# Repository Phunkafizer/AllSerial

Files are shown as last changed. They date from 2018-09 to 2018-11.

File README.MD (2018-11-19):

# AllSerial
An universal sophisticated USB-serial converter
Over the course of time I had to work with many different devices which had to be connected via a kind of serial interface. There are lots of different cheap USB-serial adapters available, but no adapter was including all features I needed in a single device. Every USB-serial adapter has in common the USB Controller. So I came up with the idea having a masterboard providing all the common features like USB interface, isolation and diagnostic elements. The most used interfaces (RS232, RS485, TTL UART, TTY current loop & LIN) are build up on slave modules which can be plugged into the mainboard. If a custom interface is needed, there is an EAGLE lib available making it easy to it on your own. 

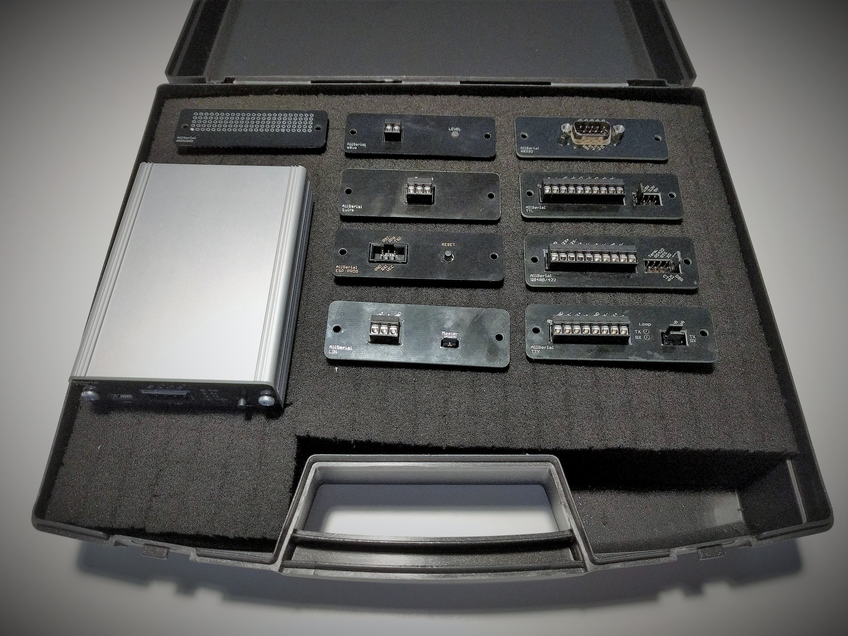
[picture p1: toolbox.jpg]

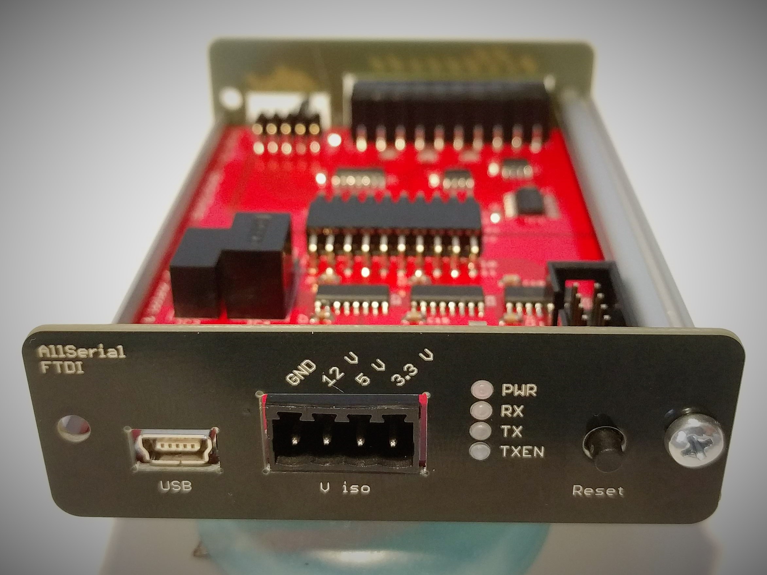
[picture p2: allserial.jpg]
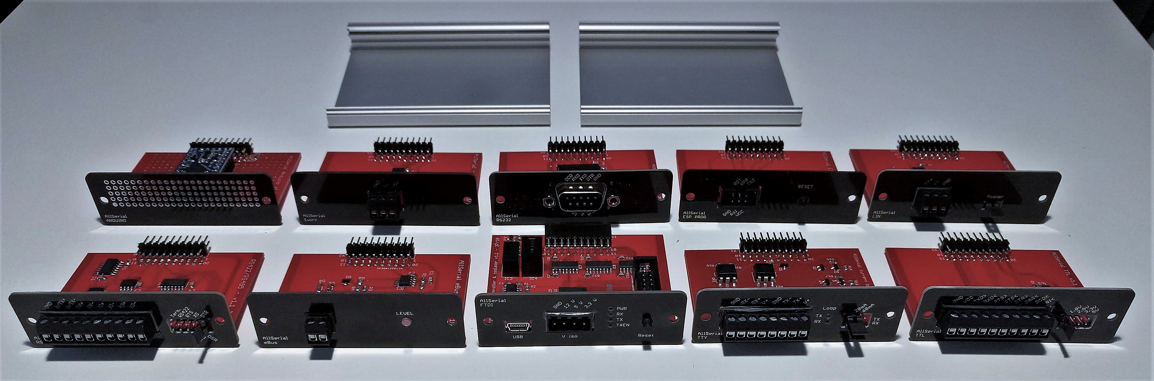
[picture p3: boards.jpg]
 

## Features
- Open source
- Isolated
- Reset button for reenumerating device on the USB
- Status LEDs (RX, TX, Power, TXEN)
- modular, just exchange daughterboard for different interfaces
- RS232 completley connected (RXD, TXD, RTS, CTS, DTR, DSR, RI, DCD)
- RS485, RS422 with Handshake
- TTY current loop 4/3/2 wire active/passive
- LIN
- TTL 1.8/2.5/3.3/5 V
- EAGLE lib for easily creating custom modules

# Modules (tested & working)
* [Mainboard FT232](1A_MAIN_FTDI/)
* [RS 422/485](2_RS485_RS422/)
* [RS 232](3_RS232/)
* [TTL](4_TTL/)
* [TTY current loop](5_TTY/)
* [LIN](6_LIN/)
* [eBus](8_eBus/)
* [1wire (with DS2480B)](9_1wire/)
* [Arduino pro mini clone for custom interfaces](10_ARDUINO/)
* [Programmer for ESP8266 (auto reset&boot)](11_ESP/)

# Modules (planned)
* mBus master

# Software
* [hterm](http://www.der-hammer.info/terminal/) (windows)
* [putty](https://www.chiark.greenend.org.uk/~sgtatham/putty/latest.html) (windows/unix)

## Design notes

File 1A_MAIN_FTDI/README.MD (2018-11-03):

# AllSerial Mainboard FT232
AllSerial Mainboard with FTDI FT232

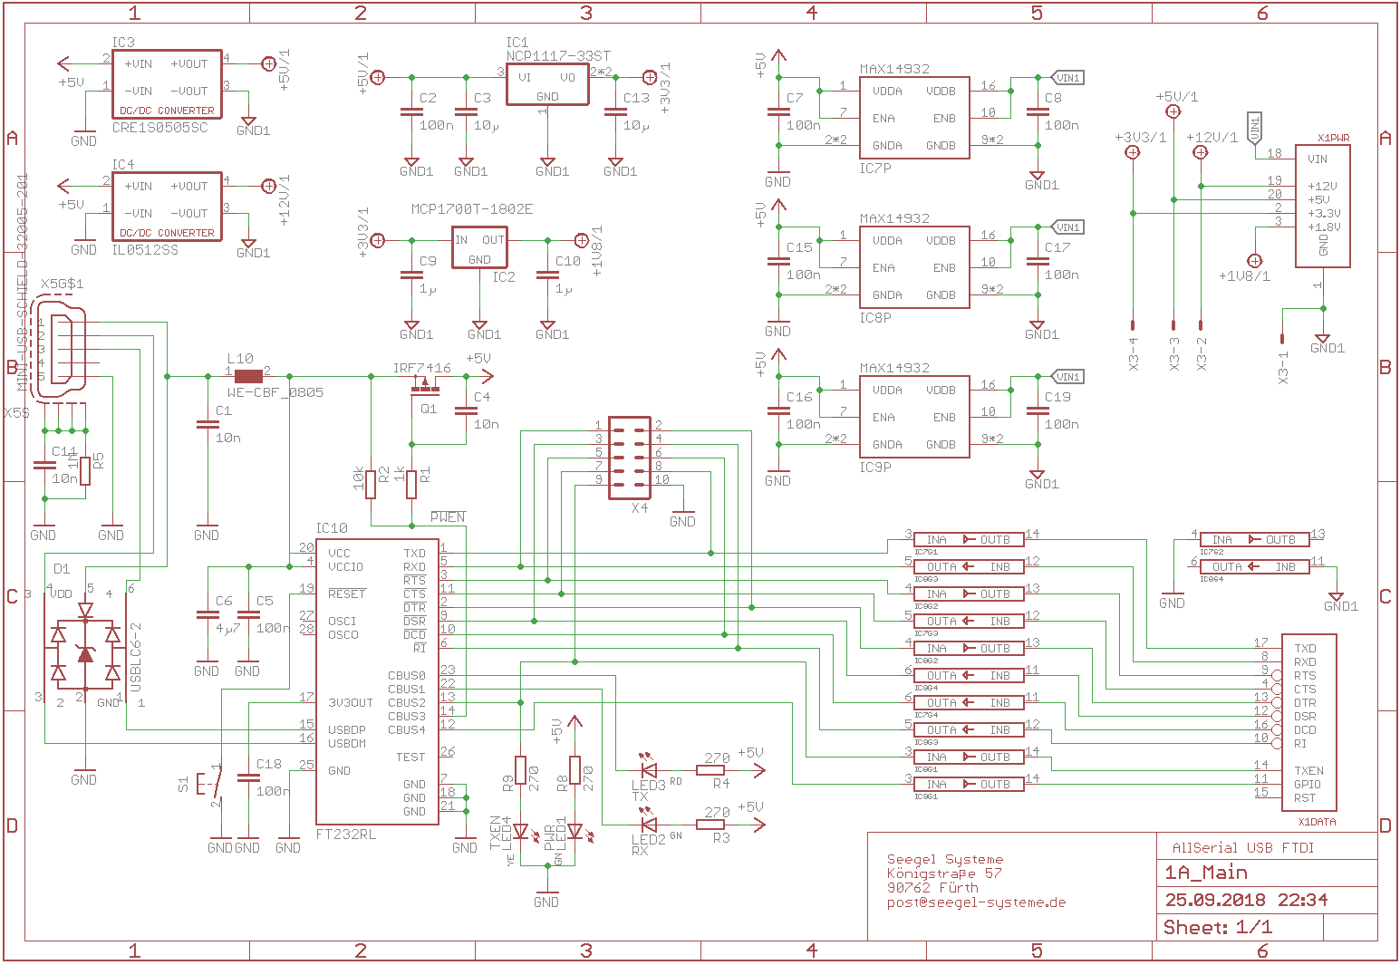
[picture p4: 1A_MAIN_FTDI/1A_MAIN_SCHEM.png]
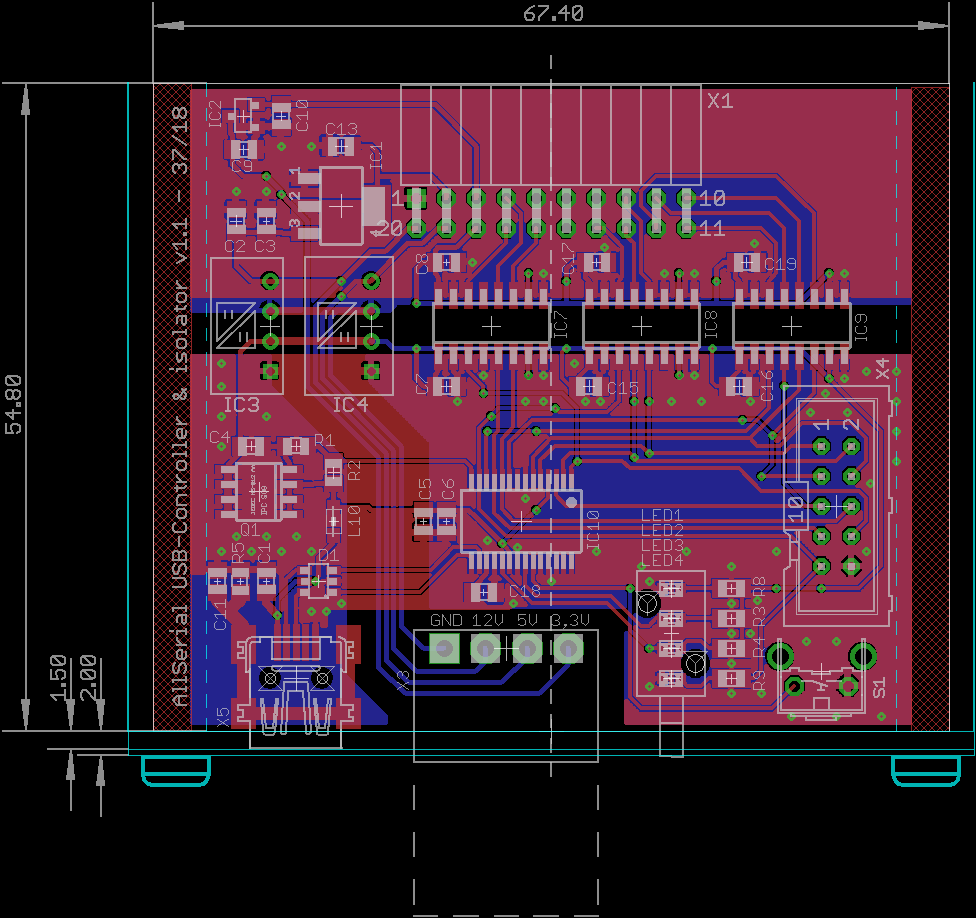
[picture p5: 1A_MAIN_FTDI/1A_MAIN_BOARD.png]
 

* Isolated between controller and daughterboards
* Connector for isolated supply 3.3 / 5 / 12 V
* LEDs for TX/RX/POWER
* 10 pin connector for logic analyser
* Reset button for reenumerating device
* Disconnects power on USB standby

Reichelt Warenkorb: https://www.reichelt.de/my/1489962

USB hardware design guide for FTDI ICs: https://www.ftdichip.com/Support/Documents/AppNotes/AN_146_USB_Hardware_Design_Guidelines_for_FTDI_ICs.pdf

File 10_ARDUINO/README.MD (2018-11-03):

# 10 development board for Arduino Pro Mini

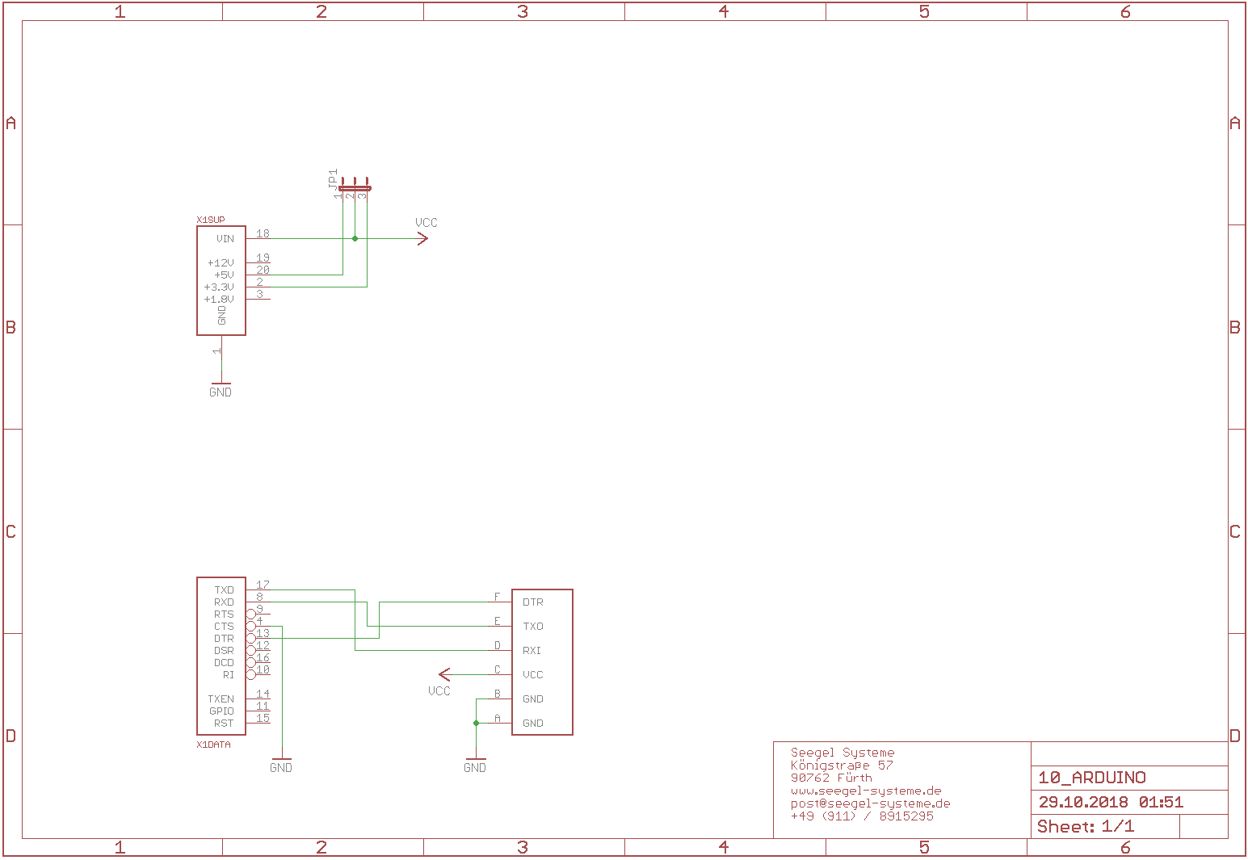
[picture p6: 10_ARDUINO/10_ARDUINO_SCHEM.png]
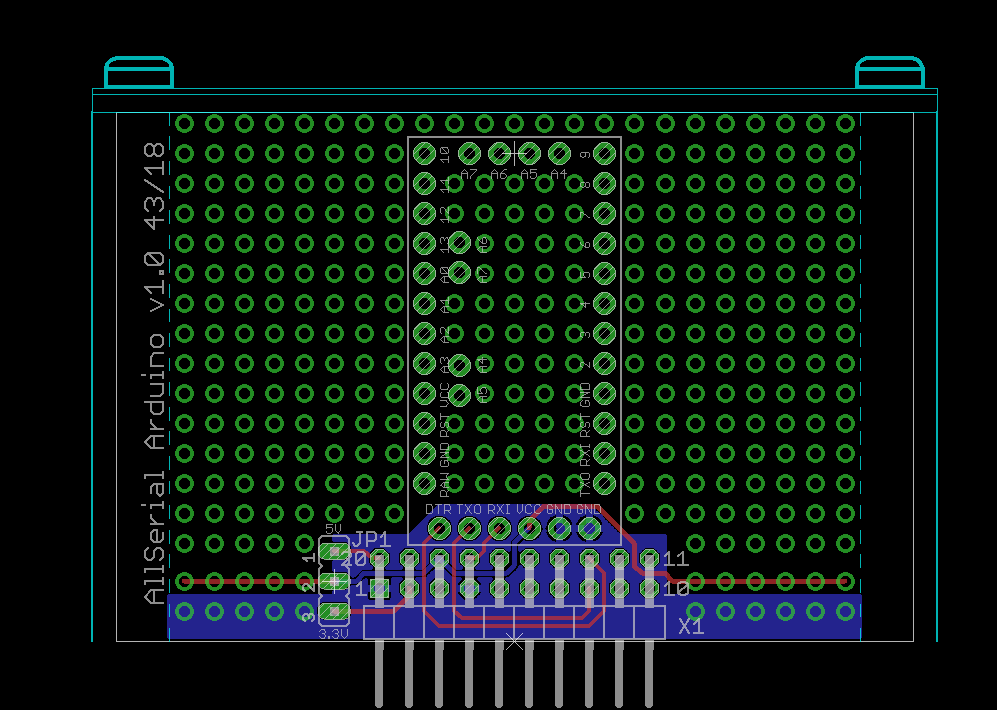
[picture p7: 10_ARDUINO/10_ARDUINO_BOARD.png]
 
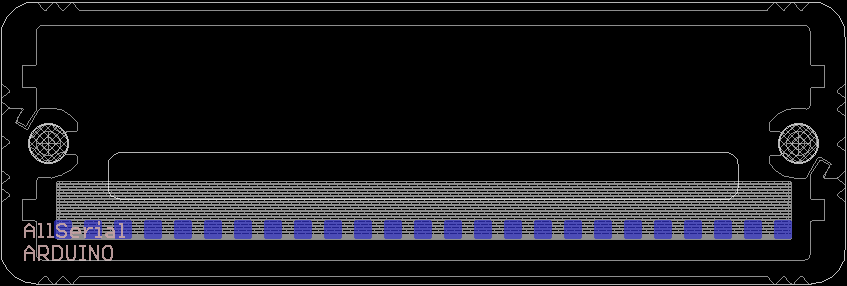
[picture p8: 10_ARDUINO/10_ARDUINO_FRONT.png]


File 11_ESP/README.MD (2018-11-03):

# 11 programmer for ESP32

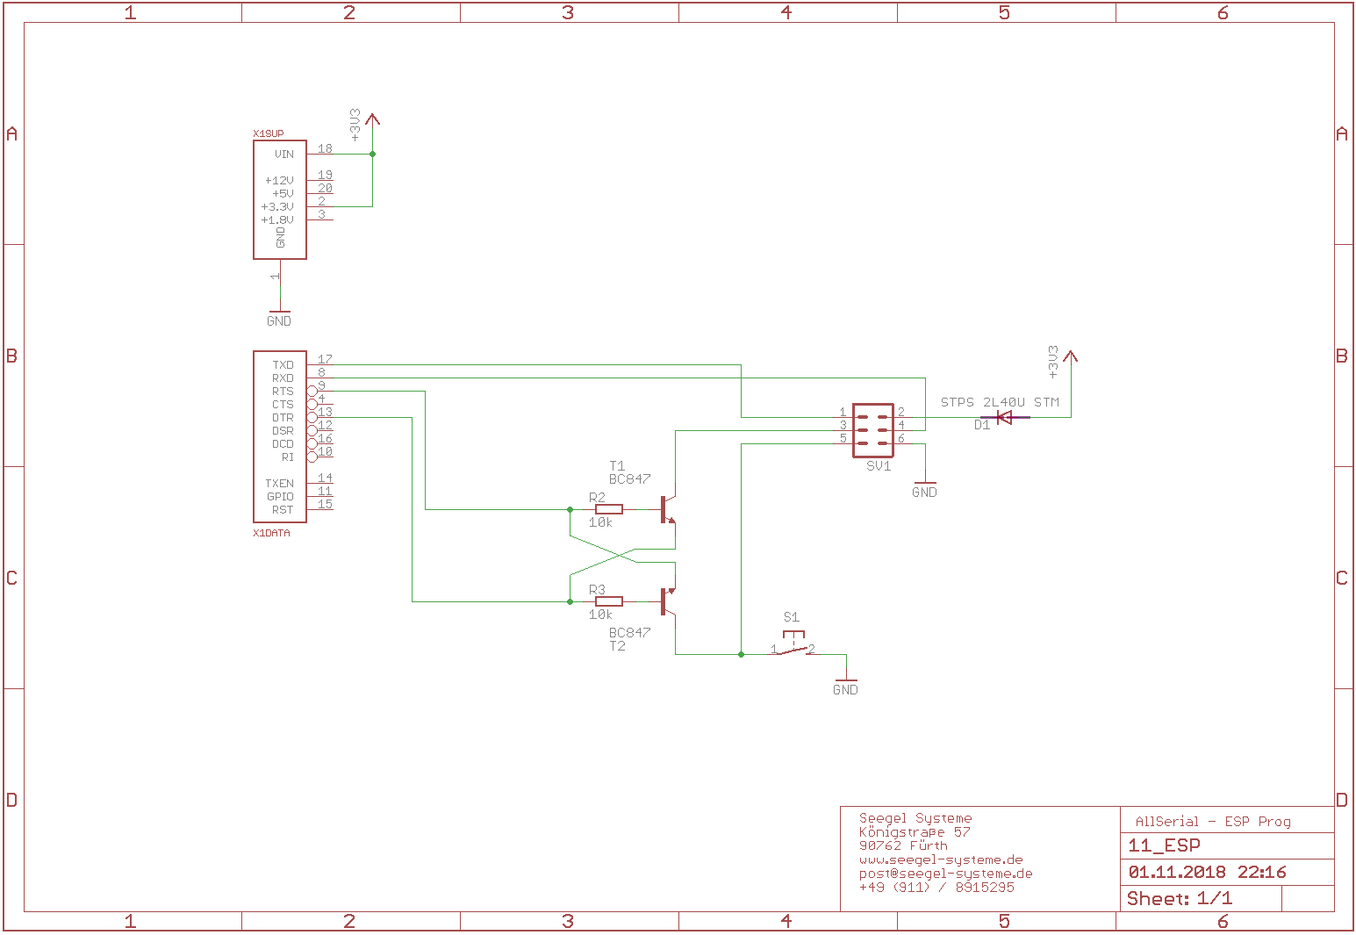
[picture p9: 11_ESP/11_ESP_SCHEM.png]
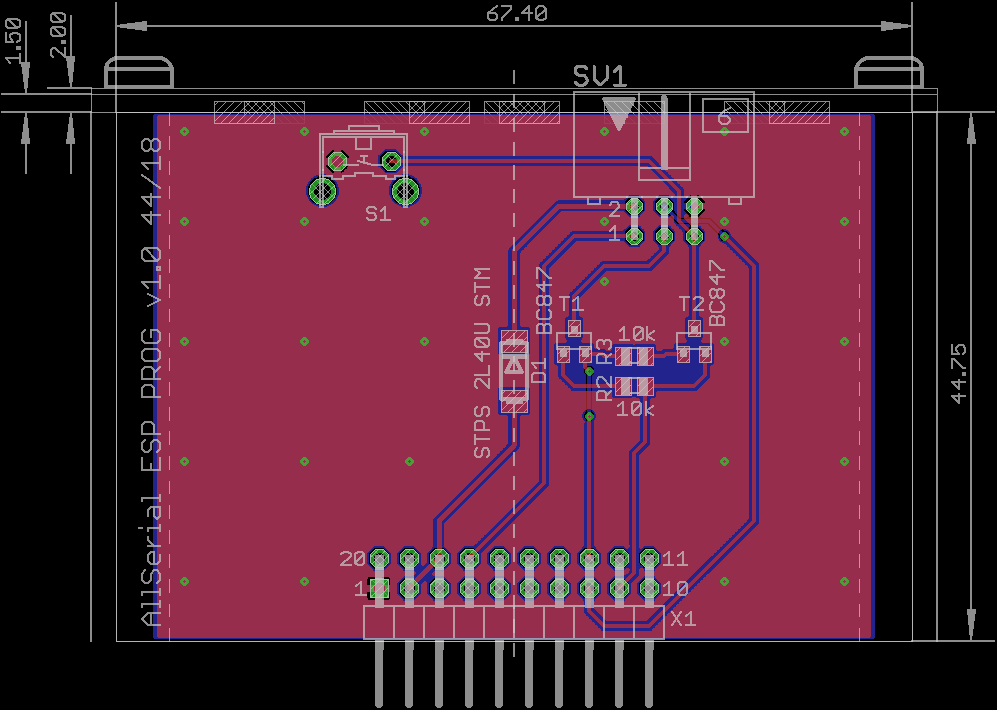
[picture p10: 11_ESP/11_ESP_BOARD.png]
 
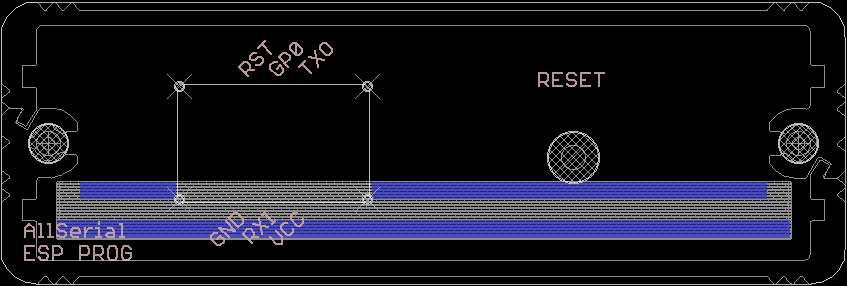
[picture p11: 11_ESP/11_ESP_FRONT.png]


* controls reset & gpio0 lines

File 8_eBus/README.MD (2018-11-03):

# 8 eBus
provides a eBus interface

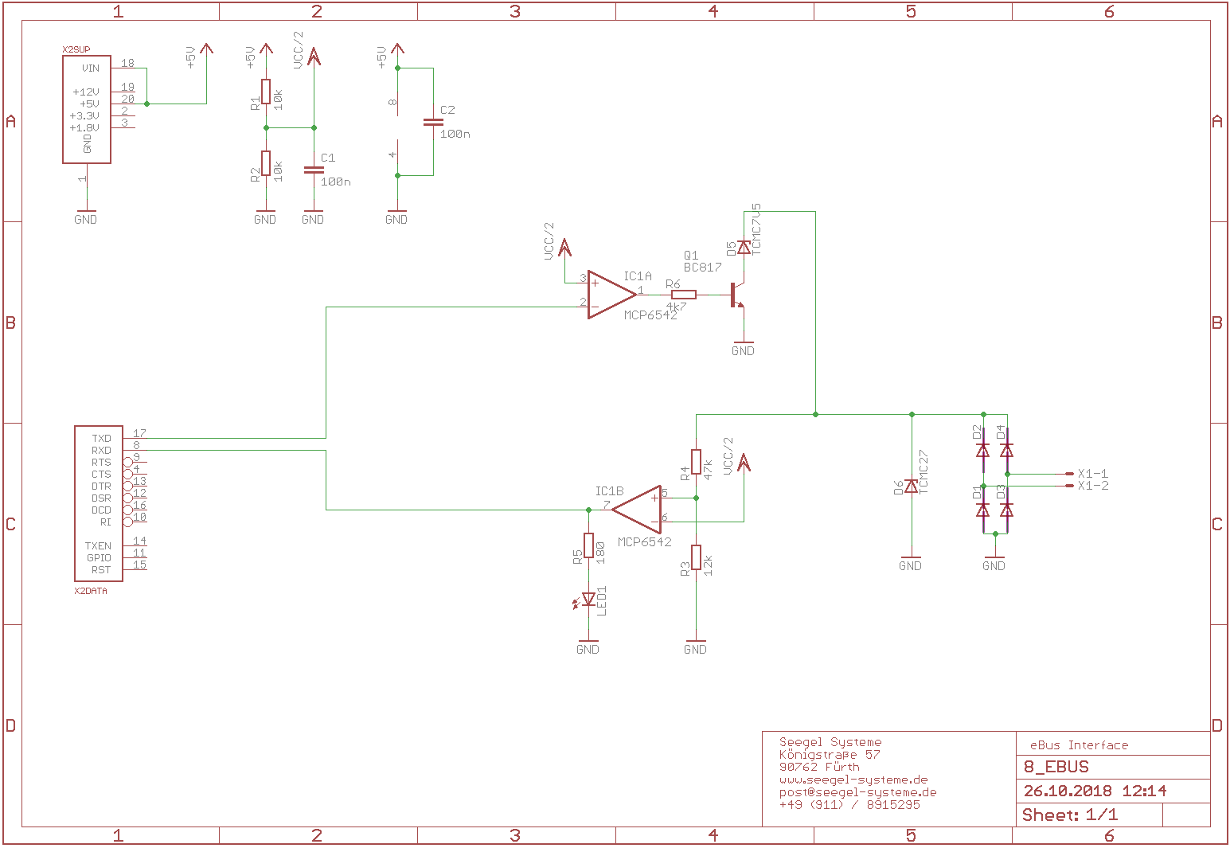
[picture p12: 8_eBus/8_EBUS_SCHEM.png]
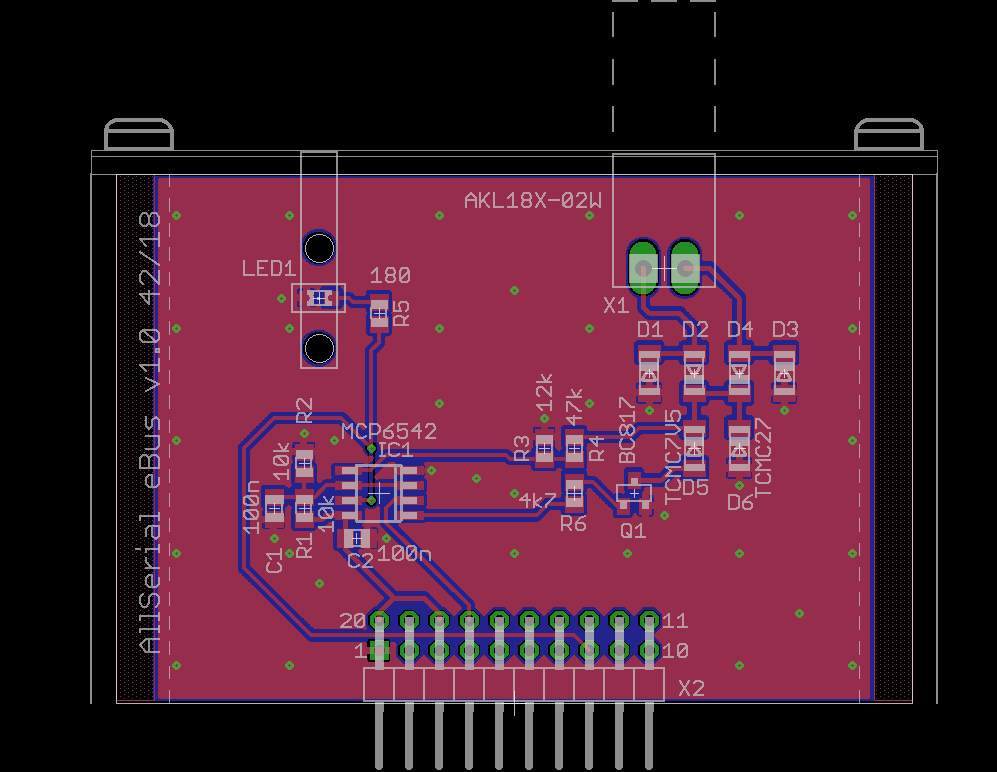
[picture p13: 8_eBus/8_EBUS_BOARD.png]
 
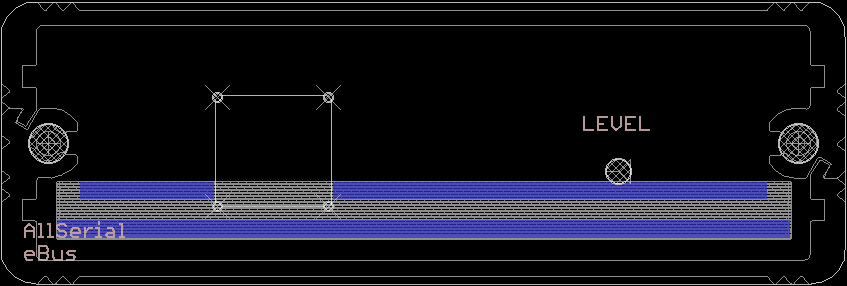
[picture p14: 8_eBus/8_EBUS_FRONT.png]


* no level adjustment needed
* LED for state of level

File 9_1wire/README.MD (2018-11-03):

# 9 1wire
provides a 1-wire interface

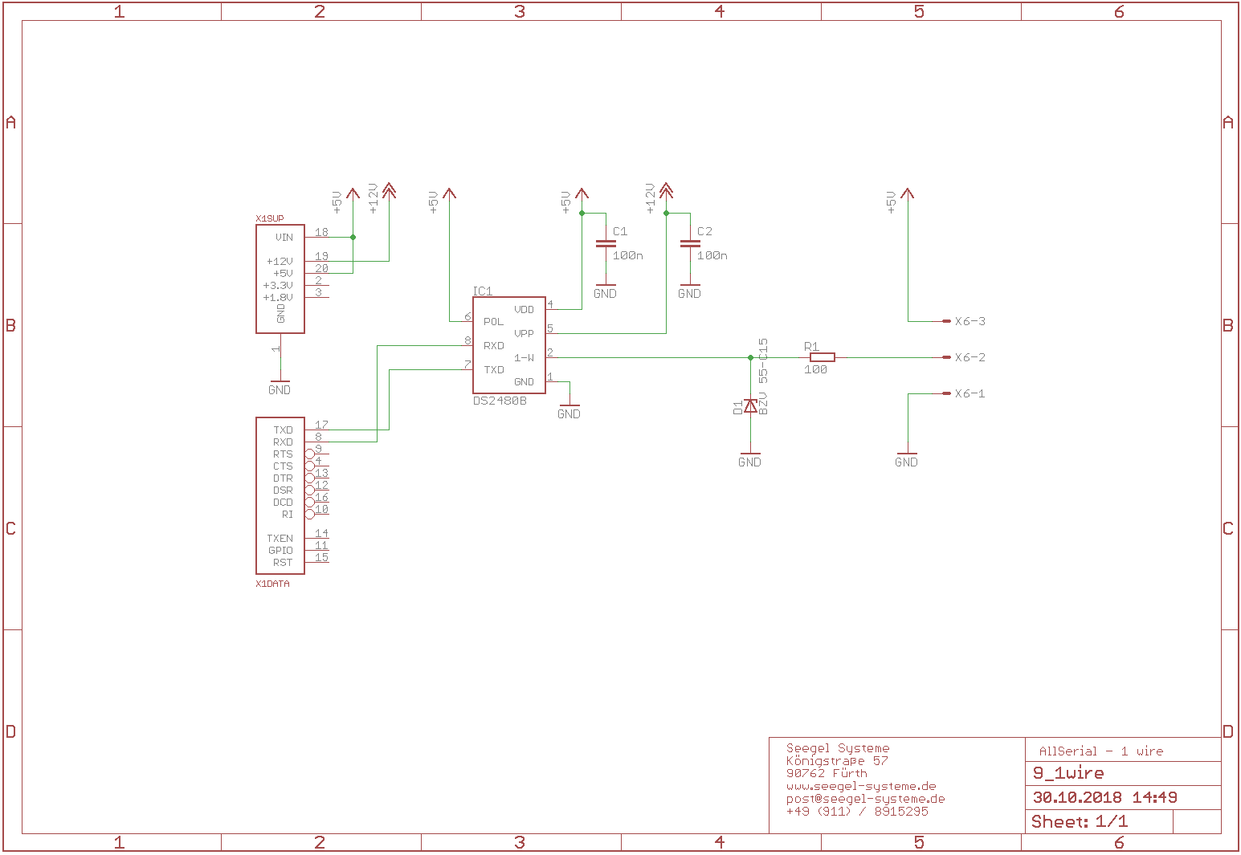
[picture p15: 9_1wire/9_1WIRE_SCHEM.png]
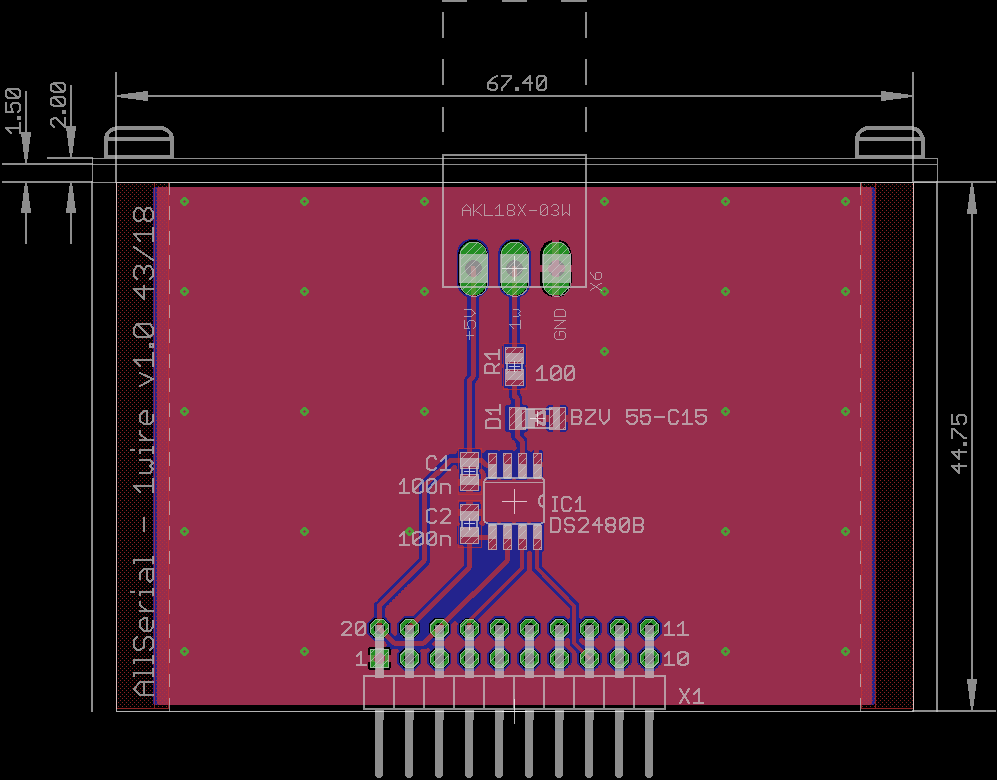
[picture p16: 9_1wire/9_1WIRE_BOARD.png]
 
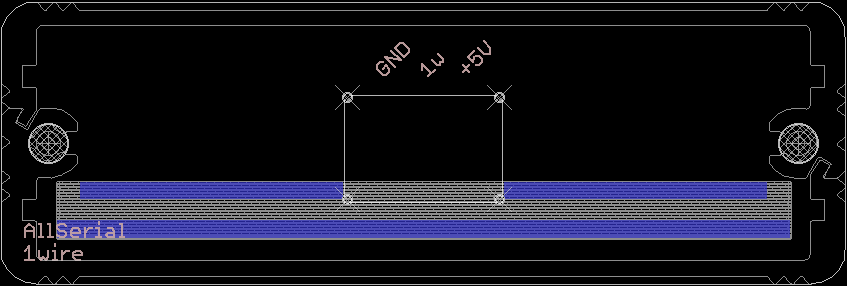
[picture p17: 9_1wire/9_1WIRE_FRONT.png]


* using IC DS2480B
* provides 12 V for programming 1wire eeproms

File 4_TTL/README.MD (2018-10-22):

# TTL connector
The TTL connector module provides all UART pins on a 3.5 mm screwclamp

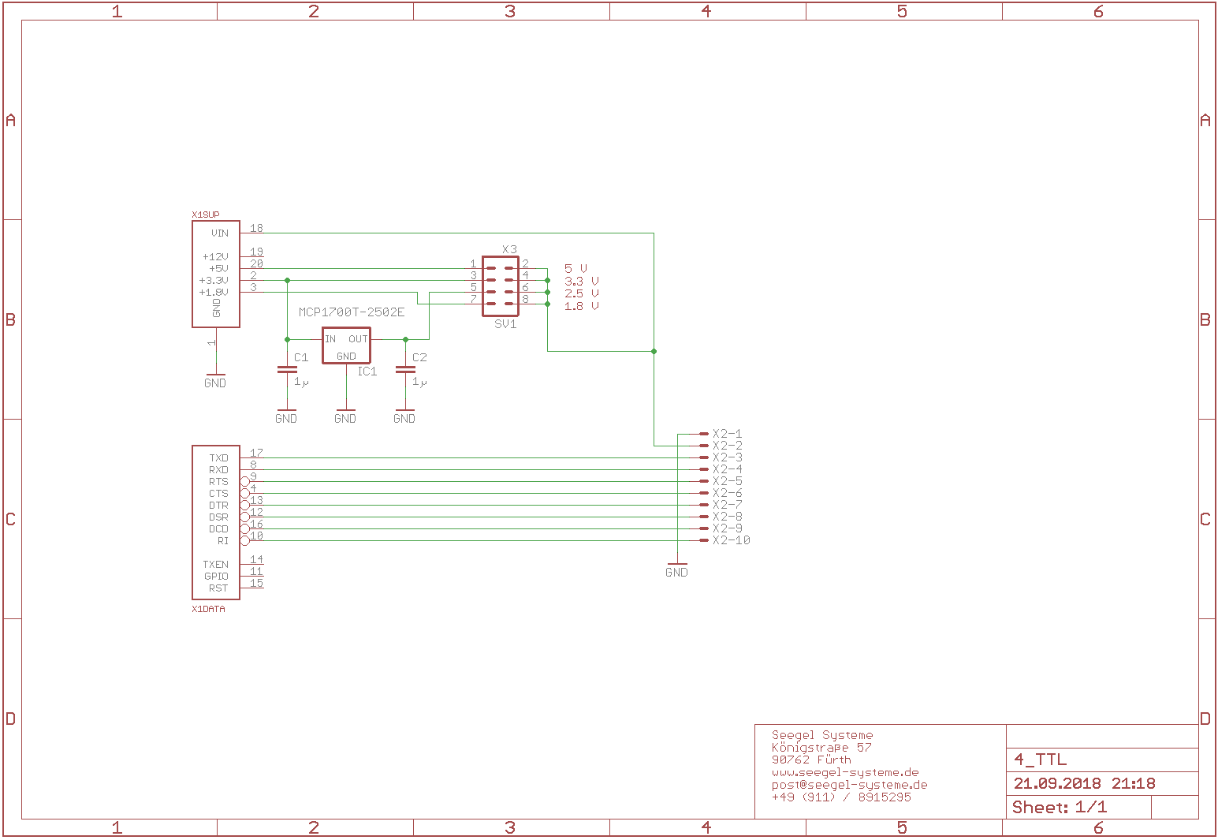
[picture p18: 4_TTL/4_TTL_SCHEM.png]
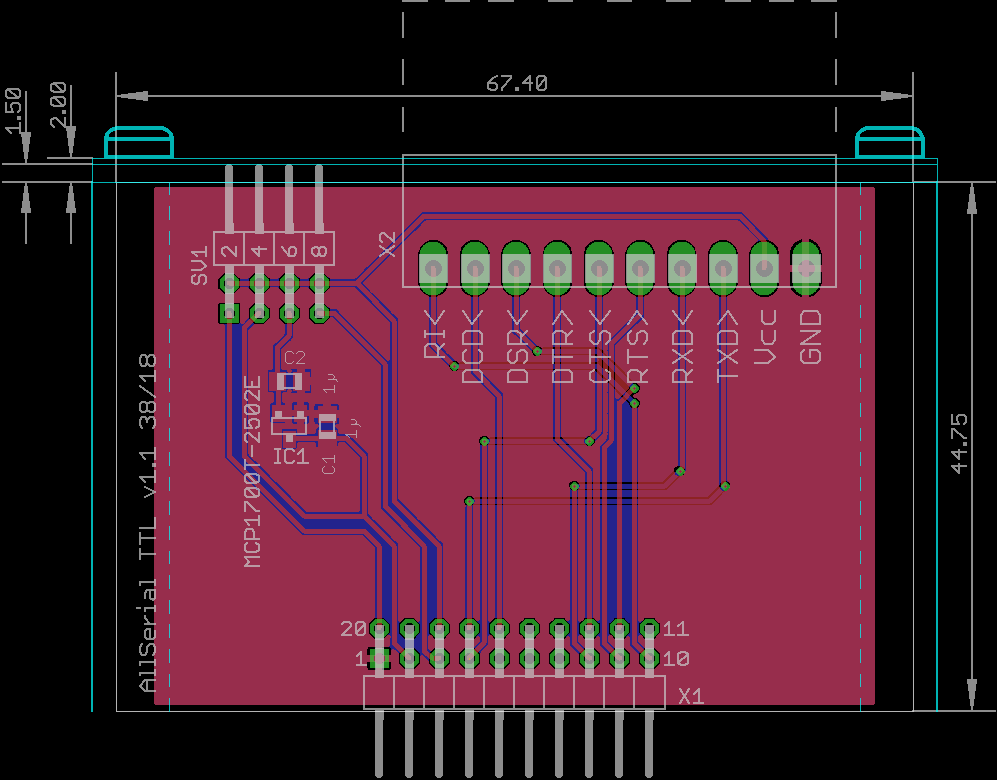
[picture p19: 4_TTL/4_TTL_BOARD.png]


* Full connection: TXD, RXD, CTS, RTS, DTR, DSR, DCD, RI
* Selectable voltage 5 V, 3.3 V, 2.5 V, 1.8 V, external

Reichelt Warenkorb: https://www.reichelt.de/my/1490024

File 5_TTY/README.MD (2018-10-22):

# Current loop (TTY) interface

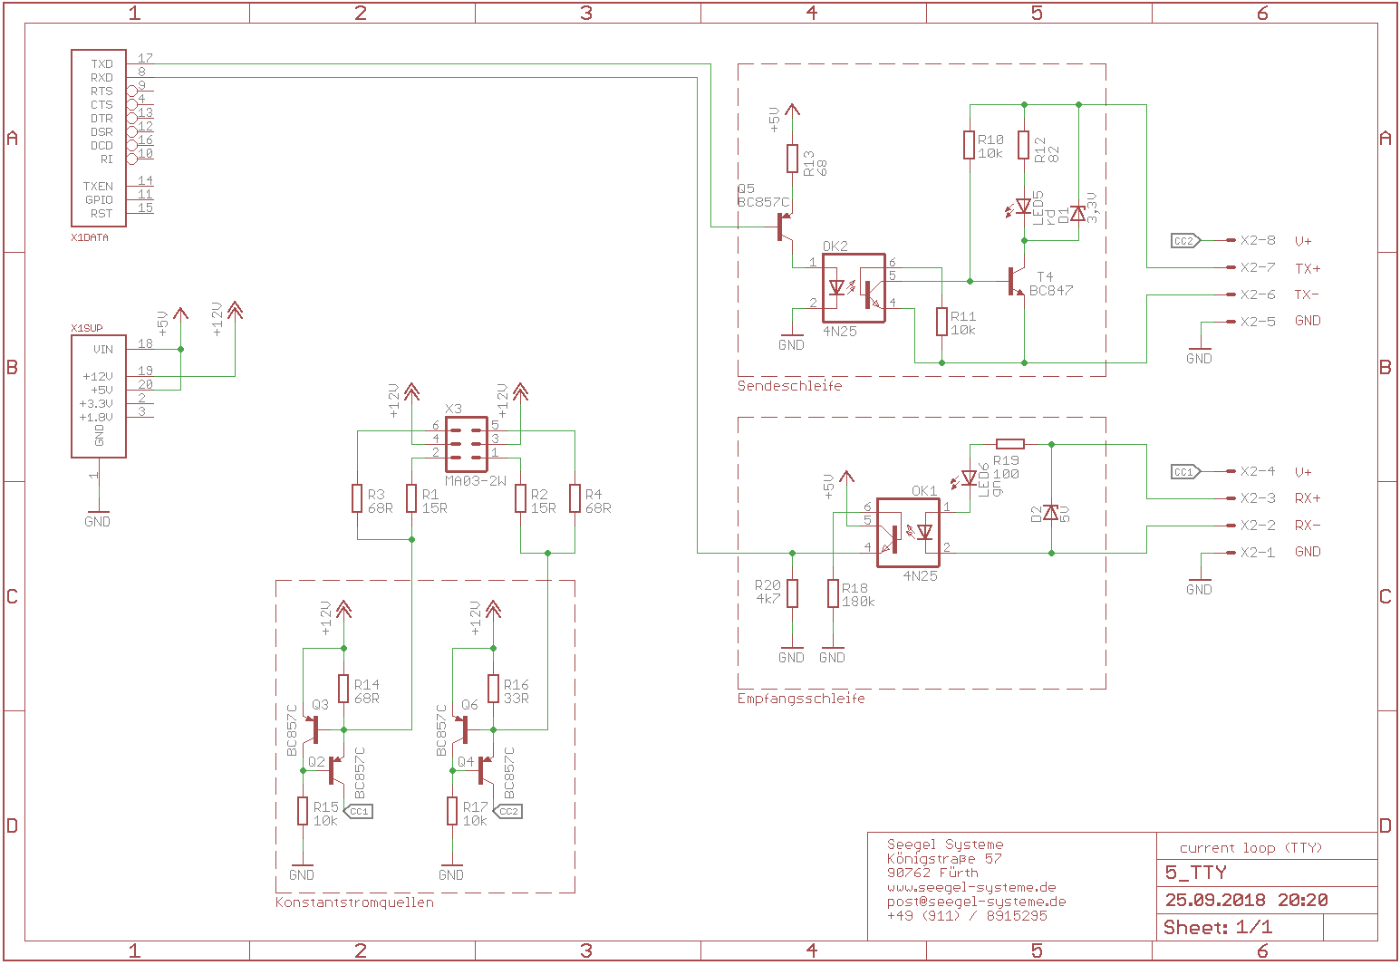
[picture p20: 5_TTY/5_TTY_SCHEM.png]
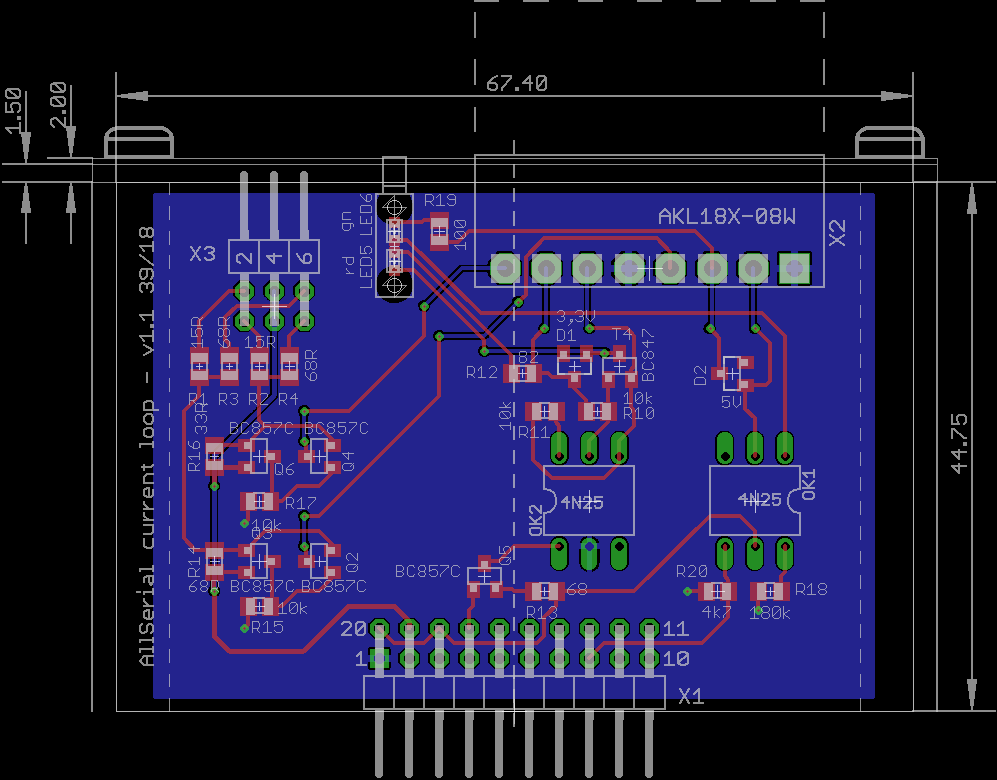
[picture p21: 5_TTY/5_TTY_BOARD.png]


* Jumper for mode (2/3/4-wire, passiv/active)
* Jumper for currentselection (5 / 20 / 60 mA)

Reichelt Warenkorb: https://www.reichelt.de/my/1490298

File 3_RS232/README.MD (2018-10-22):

# RS232
Provides a RS 422 interface (DTE)

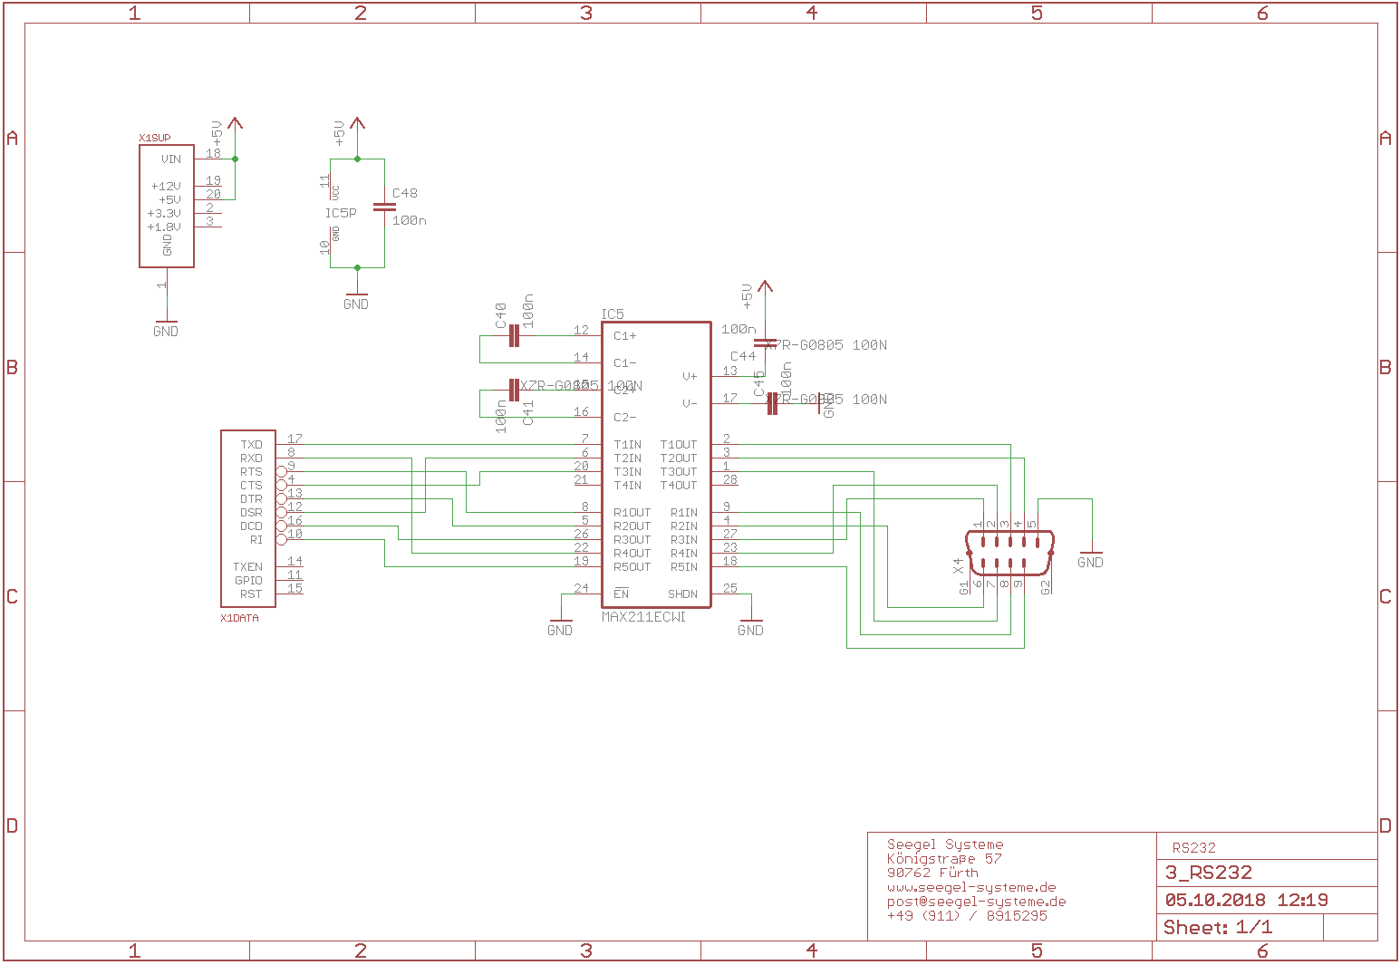
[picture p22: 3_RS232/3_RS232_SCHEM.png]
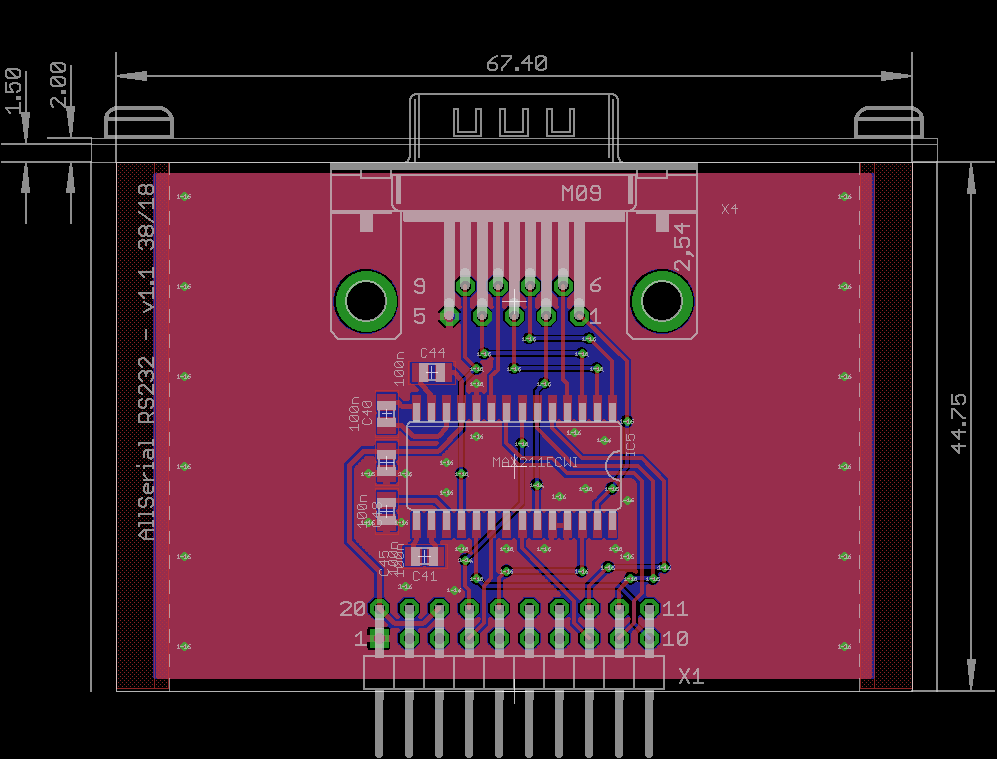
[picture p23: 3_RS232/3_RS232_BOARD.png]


* fully connected (TX, RX, RTS, CTS, DTR, DSR, RI, DCD)
* 9 pin D-SUB male connector

Reichelt Warenkorb: https://www.reichelt.de/my/1490023

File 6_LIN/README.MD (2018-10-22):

# 6 LIN
provides a LIN interface

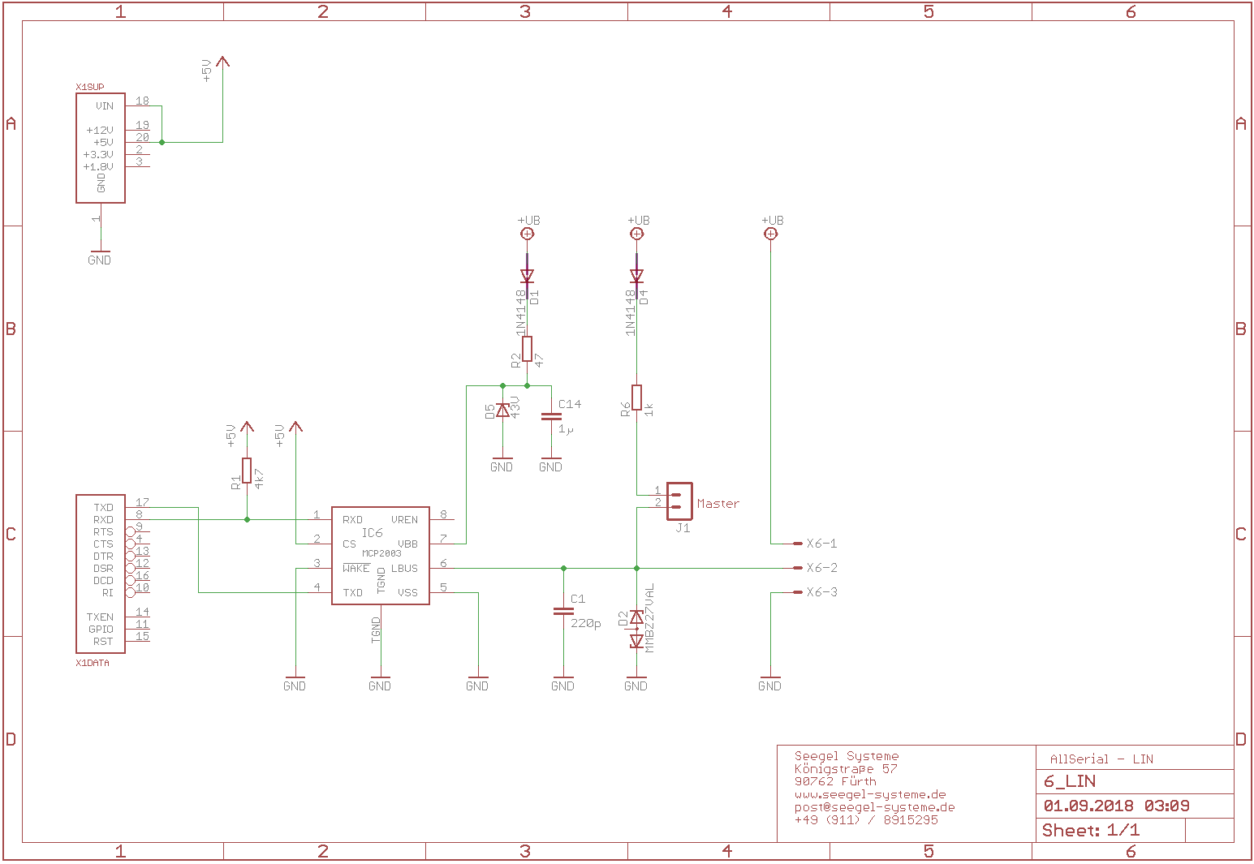
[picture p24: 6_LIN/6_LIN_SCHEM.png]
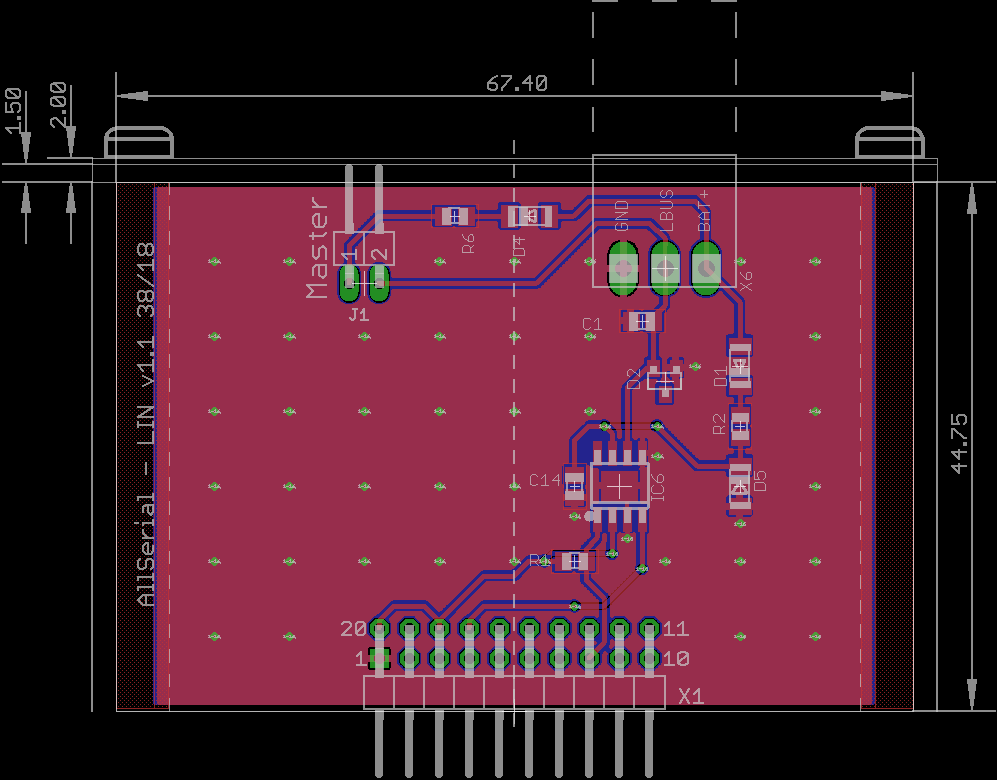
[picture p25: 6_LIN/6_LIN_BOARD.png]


* Jumper for operate as master

Reichelt Warenkorb: https://www.reichelt.de/my/1512118

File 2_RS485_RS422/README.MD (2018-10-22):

# AllSerial RS 422/485 module
Provides a RS 485/422 interface

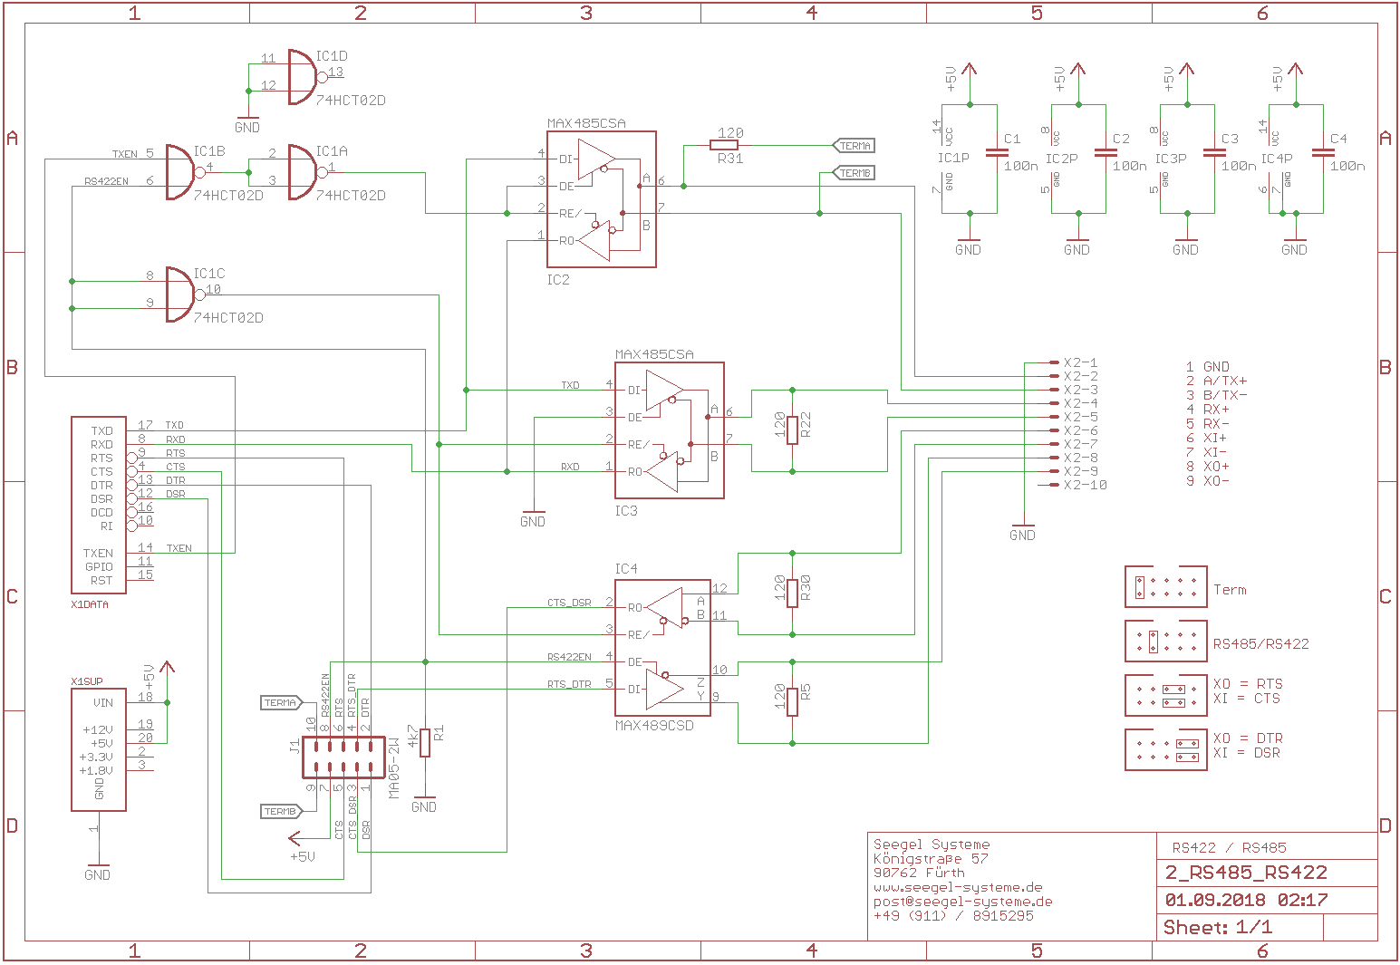
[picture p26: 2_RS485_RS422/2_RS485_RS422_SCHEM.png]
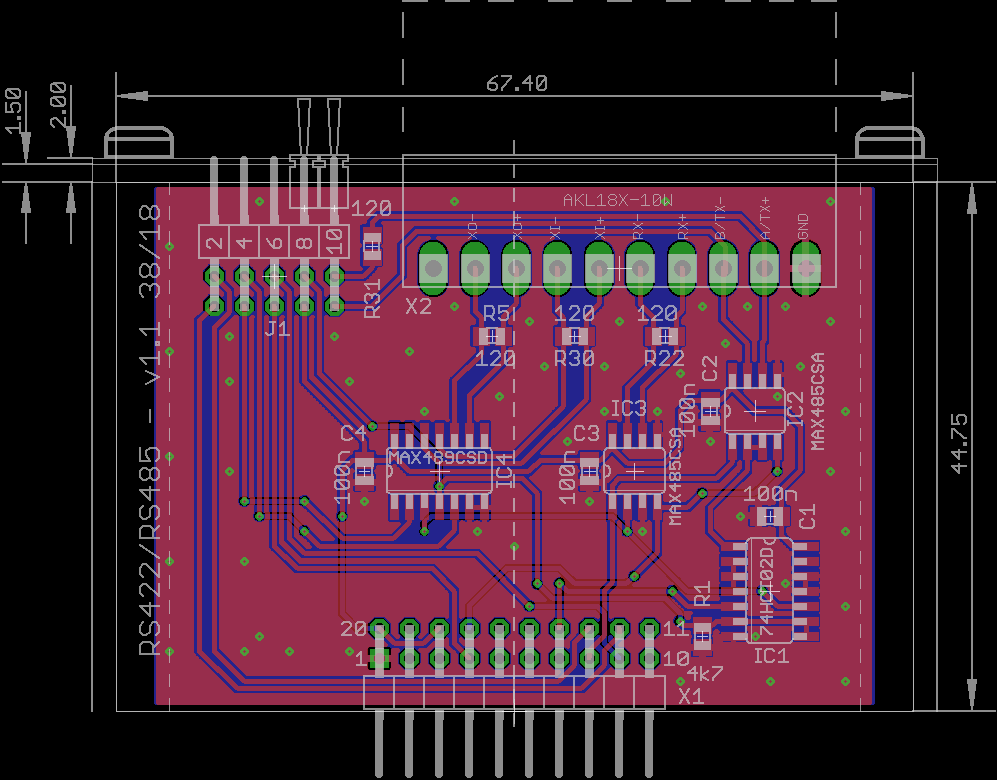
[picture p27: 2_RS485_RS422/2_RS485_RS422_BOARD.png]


* Jumper for termination
* Additional doublepair for RS422 with handshake lines
* RTS/DTR CTS/DSR for handshake can be select with jumper

Reichelt Warenkorb: https://www.reichelt.de/my/1489968

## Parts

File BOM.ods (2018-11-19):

Board | Qty | Value | Device | Package | Parts | Description | OC_REICHELT | OC_FARNELL | PRICE | PRICE_SUM | Unique | Pads
1A_MAIN
 | 1 | 1k | R-EU_R0805 | R0805 | R1 | RESISTOR, European symbol | SMD-0805 1,00K |  | 0,03 € | 0,03 € | 1 | 2
 | 1 | 10k | R-EU_R0805 | R0805 | R2 | RESISTOR, European symbol | SMD-0805 10,0K |  | 0,03 € | 0,03 € | 1 | 2
 | 4 | 270 | R-EU_R0805 | R0805 | R3, R4, R8, R9 | RESISTOR, European symbol | SMD-0805 270 |  | 0,03 € | 0,12 € | 1 | 2
 | 1 | 1M | R-EU_R0805 | R0805 | R5 | RESISTOR, European symbol | SMD-0805 1,00M |  | 0,03 € | 0,03 € | 1 | 2
 | 3 | 10n | C-EUC0805 | C0805 | C1, C4 | CAPACITOR, European symbol | X7R-G0805 10N |  | 0,01 € | 0,03 € | 1 | 2
 | 9 | 100n | C-EUC0805 | C0805 | C2, C5, C7, C8, C15, C16, C17, C18, C19 | CAPACITOR, European symbol | X7R-G0805 100N |  | 0,03 € | 0,27 € | 1 | 2
 | 2 | 1µ | C-EUC0805 | C0805 | C9, C10 | CAPACITOR, European symbol | X7R-G0805 1,0/25 |  | 0,04 € | 0,08 € | 1 | 2
 | 1 | 4µ7 | C-EUC0805 | C0805 | C6 | CAPACITOR, European symbol | Y5V 0805 DC 4,7U |  | 0,03 € | 0,03 € | 1 | 2
 | 2 | 10µ | C-EUC0805 | C0805 | C3, C13 | CAPACITOR, European symbol | KEM X5R0805 10U |  | 0,04 € | 0,08 € | 1 | 2
 | 1 | WE-CBF_0805 | WE-CBF_0805 | 805 | L10 | SMD EMI Suppression Ferrite Beads WE-CBF | BLM21PG 300 |  | 0,04 € | 0,04 € | 1 | 2
 | 1 | USBLC6-2 | WE-TVS_82400102 | WE-TVS_SOT23-6L | D1 | TVS Diode Array WE-TVS, High Speed Series |  | 1295310 | 0,28 € | 0,28 € | 1 | 6
 | 1 | PWR | LEDCHIPLED_0603 | CHIPLED_0603 | LED1 | LED gn | EVL 19-21SYGC |  | 0,06 € | 0,06 € | 1 | 2
 | 1 | RX | LEDCHIPLED_0603 | CHIPLED_0603 | LED2 | LED gn | EVL 19-21SYGC |  | 0,06 € | 0,06 € | 1 | 2
 | 1 | TX | LEDCHIPLED_0603 | CHIPLED_0603 | LED3 | LED rd | LED EL 0603 RT |  | 0,07 € | 0,07 € | 1 | 2
 | 1 | TXEN | LEDCHIPLED_0603 | CHIPLED_0603 | LED4 | LED yl | RND 135-00046 |  | 0,05 € | 0,05 € | 1 | 2
 | 1 | IRF7416 | P-MOSFET-SO8 | SO-08 | Q1 | P-Channel MOSFET | IRF 7416 |  | 0,39 € | 0,39 € | 1 | 8
 | 3 | MAX14932BASE+ | MAX14932 | SO16 | IC7, IC8, IC9 | Digital Isolator. Alt. MAX14932AASE+ |  | 2528540 | 2,62 € | 7,86 € | 1 | 16
 | 1 | MCP1700T-1802E | MCP170X | SOT23 | IC2 | V reg 1.8 V |  | 1296591 | 0,32 € | 0,32 € | 1 | 3
 | 1 | NCP1117-33ST | NCP1117-33ST | SOT223 | IC1 | V reg 3.3 V | NCP 1117 ST33T3G |  | 0,24 € | 0,24 € | 1 | 3
 | 1 | FT232RL | FT232RL | SSOP28 | IC10 | USB serial interface | FT 232 RL |  | 2,69 € | 2,69 € | 1 | 28
 | 1 |  | ML10 | ML10 | X4 | Pin header 2x5 pin 2,54 shrouded | WSL 10G |  | 0,08 € | 0,08 € | 1 |  | 10
 | 1 | AKL18X-04W | AKL18X-04W | AKL182-04 | X3 | Riacon AKL18X Steckverbinder | AKL 182-04 |  | 0,46 € | 0,46 € | 1 |  | 4
 | 1 | CRE1S0505S3C | NME | NME | DC2 | DC-DC CONVERTER 5V / 5V | ROM-0505S | 2564448 | 6,30 € | 6,30 € | 1 |  | 4
 | 1 | IL0512S | NME | NME | DC1 | DC-DC CONVERTER 5V / 12V | RI-0512S | 8728119 | 6,89 € | 6,89 € | 1 |  | 4
 | 1 | MINI-USB-32005-201 | MINI-USB-32005-201 | 32005-201 | X2 | MINI USB-B Conector | USB BWM SMD |  | 0,24 € | 0,24 € | 1 | 9
 | 1 | ALLSERIALMM | ALLSERIALMM | ALLSERIALMM |  | Pin header fem. 2x10 pin 2,54 90° | BL 2X10W 2,54 |  | 0,27 € | 0,27 € | 1 |  | 20
 | 1 |  | 31-XX | B3F-31XX | S1 | OMRON SWITCH | TASTER 3305B |  | 0,13 € | 0,13 € | 1 |  | 6
 | 1 |  |  |  |  | Connector | AKL 169-04 |  | 0,88 € | 0,88 € | 0
 | 1 |  |  |  |  | Mentor | MEN 1296.1004 |  | 0,83 € | 0,83 € | 0
2 RS485/422
 | 4 | 100n | C-EUC0805 | C0805 | C1, C2, C3, C4 | CAPACITOR, European symbol | X7R-G0805 100N |  | 0,03 € | 0,10 € | 0 | 2
 | 4 | 120 | R-EU_R0805 | R0805 | R5, R22, R30, R31 | RESISTOR, European symbol | SMD-0805 120 |  | 0,03 € | 0,10 € | 1 | 2
 | 1 | 4k7 | R-EU_R0805 | R0805 | R1 | RESISTOR, European symbol | SMD-0805 4,70K |  | 0,03 € | 0,03 € | 1 | 2
 | 1 | 74HCT02D | 74HCT02D | SO14 | IC1 | Quad 2-input NOR gate | 74HC 02D NXP |  | 0,18 € | 0,18 € | 1 | 14
 | 1 | AKL18X-10W | AKL18X-10W | AKL182-10 | X2 | Riacon AKL18X Steckverbinder | AKL 182-10 |  | 0,83 € | 0,83 € | 1 |  | 10
 | 1 | ALLSERIALD | ALLSERIALD | DAUGHTER-THT | X1 |  | SL 2X10W 2,54 |  | 0,15 € | 0,15 € | 1 |  | 20
 | 1 | MA05-2W | MA05-2W | MA05-2W | SV1 |  | MPE 088-2-010 |  | 0,18 € | 0,18 € | 1 |  | 10
 | 2 | MAX485CSA | MAX481CSA | SO08 | IC2, IC3 | RS485 TRANSEIVER | MAX 485 CSA |  | 1,13 € | 2,27 € | 1 | 8
 | 1 | MAX489CSD | MAX489CSD | SO14 | IC4 | RS485 TRANSEIVER | MAX 489 CSD |  | 2,73 € | 2,73 € | 1 | 14
 | 1 |  |  |  |  | Connector | AKL169-08 |  | 1,39 € | 1,39 € | 0
 | 4 |  |  |  |  | Jumper | MPE 149-4-002-F4 |  | 0,05 € | 0,20 € | 0
3 RS 232
 | 1 |  | M09HP | M09HP | X4 | SUB-D | D-SUB ST 09EU |  | 0,34 € | 0,34 € | 1 |  | 11
 | 5 | 100n | C-EUC0805 | C0805 | C40, C41, C44, C45, C48 | CAPACITOR, European symbol | X7R-G0805 100N |  | 0,03 € | 0,13 € | 0 | 2
 | 1 | ALLSERIALD | ALLSERIALD | DAUGHTER-THT | X9 |  | SL 2X10W 2,54 |  | 0,15 € | 0,15 € | 0
 | 1 | MAX211ECWI | MAX211ECWI | SO28L | IC5 | RS232 TRANSCEIVER |  | 2511832 | 4,34 € | 4,34 € | 1 | 28
4 TTL
 | 2 | 1µ | C-EUC0805K | C0805K | C1, C2 | CAPACITOR, European symbol | X7R-G0805 1,0/25 |  | 0,04 € | 0,08 € | 0 | 2
 | 1 | AKL18X-10W | AKL18X-10W | AKL182-10 | X2 | Riacon AKL18X Steckverbinder | AKL 182-10 |  | 0,83 € | 0,83 € | 0 |  | 10
 | 1 | ALLSERIALSLAVE | ALLSERIALSLAVE | DAUGHTER-THT | X1 |  | SL 2X10W 2,54 |  | 0,15 € | 0,15 € | 0 |  | 20
 | 1 | MCP1700T-2502E | MCP170X | SOT23 | IC1 |  |  | 1605553 | 0,32 € | 0,32 € | 1 | 3
 | 1 | X3 | MA04-2W | MA04-2W | SV1 | PIN HEADER | MPE 088-2-008 |  | 0,23 € | 0,23 € | 1 |  | 8
 | 1 |  |  |  |  | Connector | AKL 169-10 |  | 1,67 € | 1,67 € | 0
 | 1 |  |  |  |  | Jumper | MPE 149-4-002-F4 |  | 0,05 € | 0,05 € | 0
5 TTY
 | 1 |  |  |  | X1 | PIN HEADER | SL 2X10W 2,54 |  | 0,15 € | 0,15 € | 0 |  | 20
 | 1 |  | MA08-2W | MA08-2W | X3 |  | MPE 088-2-006 |  | 0,17 € | 0,17 € | 1 |  | 16
 | 1 | 100 | R-EU_R0805 | R0805 | R19 | RESISTOR, European symbol | SMD-0805 100 |  | 0,03 € | 0,03 € | 1 | 2
 | 2 | 10k | R-EU_R0805 | R0805 | R10, R11 | RESISTOR, European symbol | SMD-0805 10,0K |  | 0,13 € | 0,25 € | 0 | 2
 | 2 | 10k | R-EU_R0805 | R0805 | R15, R17 | RESISTOR, European symbol | SMD-0805 10,0K |  | 0,13 € | 0,25 € | 0 | 2
 | 2 | 15R | R-EU_R0805 | R0805 | R1, R2 | RESISTOR, European symbol | SMD-0805 15,0 |  | 0,03 € | 0,05 € | 1 | 2
 | 1 | 180k | R-EU_R0805 | R0805 | R18 | RESISTOR, European symbol | SMD-0805 180K |  | 0,03 € | 0,03 € | 1 | 2
 | 1 | 3,3V | ZENER-DIODESOT23 | SOT23 | D1 | Z-Diode | SMD ZD 3,3 |  | 0,03 € | 0,03 € | 1 | 2
 | 1 | 33R | R-EU_R0805 | R0805 | R16 | RESISTOR, European symbol | SMD-0805 33,0 |  | 0,03 € | 0,03 € | 1 | 2
 | 2 | 4N25 | 4N35 | DIL06 | OK1, OK2 | MOTOROLA OPTO COUPLER | 4N 25 |  | 0,42 € | 0,84 € | 1 |  | 6
 | 1 | 4k7 | R-EU_R0805 | R0805 | R20 | RESISTOR, European symbol | SMD-0805 4,70K |  | 0,03 € | 0,03 € | 0 | 2
 | 1 | 5V | ZENER-DIODESOT23 | SOT23 | D2 | Z-Diode | SMD ZD 5,1 |  | 0,03 € | 0,03 € | 1 | 2
 | 1 | 68 | R-EU_R0805 | R0805 | R13 | RESISTOR, European symbol | SMD-0805 68,0 |  | 0,03 € | 0,03 € | 1 | 2
 | 3 | 68 | R-EU_R0805 | R0805 | R3, R4, R14 | RESISTOR, European symbol | SMD-0805 68,0 |  | 0,03 € | 0,08 € | 0 | 2
 | 1 | 82 | R-EU_R0805 | R0805 | R12 | RESISTOR, European symbol | SMD-0805 82,0 |  | 0,03 € | 0,03 € | 1 | 2
 | 1 | AKL18X-08W | AKL18X-08W | AKL182-08 | X2 | Riacon AKL18X Steckverbinder | AKL 182-08 |  |  | 0,00 € | 1 |  | 8
 | 1 |  |  |  |  | Riacon Anschlussklemme | AKL 169-08 |  | 1,39 € | 1,39 € | 0
 | 1 | BC847 | BC847 | SOT23 | T4 | NPN TRANSISTOR | BC 847CW SMD |  | 0,03 € | 0,03 € | 1 | 3
 | 5 | BC857C | BC857CSMD | SOT23-BEC | Q2, Q3, Q4, Q5, Q6 | PNP Transistror | BC 857 NXP |  | 0,08 € | 0,42 € | 1 | 3
 | 1 | gn | LEDCHIPLED_0603 | CHIPLED_0603 | LED6 | LED | LED EL 0603 GR2 |  | 0,13 € | 0,13 € | 0 | 2
 | 1 | rd | LEDCHIPLED_0603 | CHIPLED_0603 | LED5 | LED | LED EL 0603 RT |  | 0,07 € | 0,07 € | 0 | 2
 | 1 |  |  |  |  |  | MEN 1296.2012 |  | 0,49 € | 0,49 € | 0
 |  |  |  |  |  | Jumper | MPE 149-4-002-F0 |  | 0,05 € | 0,00 € | 0
6 LIN
 | 1 |  | MA02-1W | MA02-W | J1 |  | SL 1X36W 2,54 |  | 0,18 | 0,18 € | 1 |  | 2
 | 2 | 1N4148 | DIODE-MINIMELF | MINIMELF | D1, D4 | DIODE | 1N 4148 SMD |  | 0,01 | 0,02 € | 1 | 2
 | 1 | 1k | R-EU_R0805 | R0805 | R6 | RESISTOR, European symbol | RND 0805 1 1,0 K |  | 0,02 | 0,02 € |  | 2
 | 1 | 1µ | C-EUC0805 | C0805 | C14 | CAPACITOR, European symbol | KEM X7R0805A1,0U |  | 0,05 | 0,05 € | 0 | 2
 | 1 | 220p | C-EUC0805 | C0805 | C1 | CAPACITOR, European symbol | NPO-G0805 220P |  | 0,03 | 0,03 € | 1 | 2
 | 1 | 43V | ZENER-DIODESOD80C | SOD80C | D5 | Z-Diode | SMD ZF 43 |  | 0,02 | 0,02 € | 1 | 2
 | 1 | 47 | R-EU_R0805 | R0805 | R2 | RESISTOR, European symbol | SMD-0805 47,0 |  | 0,03 | 0,03 € | 1 | 2
 | 1 | 4k7 | R-EU_R0805 | R0805 | R1 | RESISTOR, European symbol | RND 0805 1 4,7K |  | 0,02 | 0,02 € | 0 | 2
 | 1 | AKL18X-03W | AKL18X-03W | AKL182-03 | X6 | Riacon AKL18X Steckverbinder | AKL 182-03 |  | 0,34 | 0,34 € | 1 |  | 3
 | 1 |  |  |  |  | Connector | AKL 169-03 |  | 0,67 | 0,67 € | 0
 | 1 | ALLSERIALSLAVE | ALLSERIALSLAVE | DAUGHTER-THT | X1 |  | SL 2X10W 2,54 |  | 0,15 € | 0,15 € | 0 |  | 20
 | 1 | MCP2003 | MCP2003 | SOIC8T | IC6 |  | MCP 2003-E/SN |  | 0,63 | 0,63 € | 1 | 8
 | 1 | MMBZ27VAL | MMBZ27VAL | SOT23 | D2 |  |  | 2924702 | 0,05 | 0,05 € | 1 | 3
 | 1 |  |  |  |  | Jumper | MPE 149-4-002-F0 |  | 0,05 € | 0,05 € | 0
 | 130 |  |  |  |  |  |  |  |  | 52,04 | 60 | 237 | 212

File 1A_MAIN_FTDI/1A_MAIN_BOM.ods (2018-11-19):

Qty | Value | Device | Package | Parts | Description | OC_REICHELT | OC_FARNELL | PRICE | PRICE_SUM
1 | 1k | R-EU_R0805 | R0805 | R1 | RESISTOR, European symbol | SMD-0805 1,00K |  | 0,03 € | 0,03 €
1 | 10k | R-EU_R0805 | R0805 | R2 | RESISTOR, European symbol | SMD-0805 10,0K |  | 0,03 € | 0,03 €
4 | 270 | R-EU_R0805 | R0805 | R3, R4, R8, R9 | RESISTOR, European symbol | SMD-0805 270 |  | 0,03 € | 0,12 €
1 | 1M | R-EU_R0805 | R0805 | R5 | RESISTOR, European symbol | SMD-0805 1,00M |  | 0,03 € | 0,03 €
3 | 10n | C-EUC0805 | C0805 | C1, C4 | CAPACITOR, European symbol | X7R-G0805 10N |  | 0,01 € | 0,03 €
9 | 100n | C-EUC0805 | C0805 | C2, C5, C7, C8, C15, C16, C17, C18, C19 | CAPACITOR, European symbol | X7R-G0805 100N |  | 0,03 € | 0,27 €
2 | 1µ | C-EUC0805 | C0805 | C9, C10 | CAPACITOR, European symbol | X7R-G0805 1,0/25 |  | 0,04 € | 0,08 €
1 | 4µ7 | C-EUC0805 | C0805 | C6 | CAPACITOR, European symbol | Y5V 0805 DC 4,7U |  | 0,03 € | 0,03 €
2 | 10µ | C-EUC0805 | C0805 | C3, C13 | CAPACITOR, European symbol | KEM X5R0805 10U |  | 0,04 € | 0,08 €
1 | WE-CBF_0805 | WE-CBF_0805 | 805 | L10 | SMD EMI Suppression Ferrite Beads WE-CBF | BLM21PG 300 |  | 0,04 € | 0,04 €
1 | USBLC6-2 | WE-TVS_82400102 | WE-TVS_SOT23-6L | D1 | TVS Diode Array WE-TVS, High Speed Series |  | 1295310 | 0,28 € | 0,28 €
1 | PWR | LEDCHIPLED_0603 | CHIPLED_0603 | LED1 | LED gn | EVL 19-21SYGC |  | 0,06 € | 0,06 €
1 | RX | LEDCHIPLED_0603 | CHIPLED_0603 | LED2 | LED gn | EVL 19-21SYGC |  | 0,06 € | 0,06 €
1 | TX | LEDCHIPLED_0603 | CHIPLED_0603 | LED3 | LED rd | LED EL 0603 RT |  | 0,07 € | 0,07 €
1 | TXEN | LEDCHIPLED_0603 | CHIPLED_0603 | LED4 | LED yl | RND 135-00046 |  | 0,05 € | 0,05 €
1 | IRF7416 | P-MOSFET-SO8 | SO-08 | Q1 | P-Channel MOSFET | IRF 7416 |  | 0,39 € | 0,39 €
3 | MAX14932BASE+ | MAX14932 | SO16 | IC7, IC8, IC9 | Digital Isolator. Alt. MAX14932AASE+ |  | 2528540 | 2,62 € | 7,86 €
1 | MCP1700T-1802E | MCP170X | SOT23 | IC2 | V reg 1.8 V |  | 1296591 | 0,32 € | 0,32 €
1 | NCP1117-33ST | NCP1117-33ST | SOT223 | IC1 | V reg 3.3 V | NCP 1117 ST33T3G |  | 0,24 € | 0,24 €
1 | FT232RL | FT232RL | SSOP28 | IC10 | USB serial interface | FT 232 RL |  | 2,69 € | 2,69 €
1 |  | ML10 | ML10 | X4 | Pin header 2x5 pin 2,54 shrouded | WSL 10G |  | 0,08 € | 0,08 €
1 | AKL18X-04W | AKL18X-04W | AKL182-04 | X3 | Riacon AKL18X Steckverbinder | AKL 182-04 |  | 0,46 € | 0,46 €
1 | CRE1S0505S3C | NME | NME | DC2 | DC-DC CONVERTER 5V / 5V | ROM-0505S | 2564448 | 6,30 € | 6,30 €
1 | IL0512S | NME | NME | DC1 | DC-DC CONVERTER 5V / 12V | RI-0512S | 8728119 | 6,89 € | 6,89 €
1 | MINI-USB-32005-201 | MINI-USB-32005-201 | 32005-201 | X2 | MINI USB-B Conector | USB BWM SMD |  | 0,24 € | 0,24 €
1 | ALLSERIALMM | ALLSERIALMM | ALLSERIALMM |  | Pin header fem. 2x10 pin 2,54 90° | BL 2X10W 2,54 |  | 0,27 € | 0,27 €
1 |  | 31-XX | B3F-31XX | S1 | OMRON SWITCH | TASTER 3305B |  | 0,13 € | 0,13 €
1 |  |  |  |  | Connector | AKL 169-04 |  | 0,88 € | 0,88 €
1 |  |  |  |  | Mentor | MEN 1296.1004 |  | 0,83 € | 0,83 €
1 |  |  |  |  | Enclosure | AKG 71 24 100 ME |  | 8,82 € | 8,82 €
 |  |  |  |  |  |  |  |  | 16,08 €

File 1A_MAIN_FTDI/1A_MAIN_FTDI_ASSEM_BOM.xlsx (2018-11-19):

 |  |  | xxxx xxxx xxxxx xxPCS BOM (Sample Bill of Materials)
Item # | *Ref Des | *Qty | Manufacturer | *Mfg Part # | Description / Value | *Package | Type | Your Instructions / Notes
1 | U1 | 1 | Linear | LTC3780EG#PBF | IC BUCK-BOOST CONV 24-SSOP | 24-SSOP | SMD
2 | U2,U4 | 2 | Fairchild | LM2904M | IC OPAMP DUAL -40-85 C 8-SOIC | 8-SOIC | DNS
3 | U3 | 1 | ON | LM317MBDTG | LM317M IC REG VOLT ADJ 500MA DPAK | DPAK | SMD
4 | U5 | 1 | Microchip | PIC16F690-I/SS | IC PIC MCU FLASH 4KX14 20SSOP | 20SSOP | SMD
5 | Q1 | 1 | Diodes Inc | GBJ10005-F | RECT BRIDGE GPP 50V 10A GBJ | GBJ | SMD
6 | R14,R18 | 2 | Panasonic | ERJ-6ENF4701V | RES 4.70K OHM 1/8W 1% 0805 SMD | 0805 | SMD
7 | R15 | 1 | Susumu | RL3720WT-R022-F | RES .022 OHM 1W 1% 0815 SMD | 0815 | SMD
8 | R16, R31 | 2 | Panasonic | ERJ-6ENF4702V | RES 47.0K OHM 1/8W 1% 0805 SMD | 0805 | SMD
9 | C5 | 1 | Murata | GRM21BR71C225KA12L | CAP CER 2.2UF 16V X7R 0805 | 0805 | SMD
10 | C7 | 1 | Murata | GRM21BR71C475KA73L | CAP CER 4.7UF 16V X7R 0805 | 0805 | DNS
11 | C8,C22 | 2 | Muruta | GRM21BR71C105KA01L | CAP CER 1.0UF 16V 10% X7R 0805 | 0805 | SMD
12 | CN6 | 1 | Molex | 538-53398-0671 | 1.25mm Connectors VERTICAL HDR SMT 6P | SMT 6P | SMD
13 | L1,L2 | 2 | Coiltronics | DR127-150-R | INDUCTOR SHIELD PWR 15UH SMD | SMD | SMD
14 | L3 | 1 | TDK | ACM1211-102-2PL-TL | CHOKE COMM MODE 1000 OHM 6A SM | SMD | SMD
15 | CN3,CN4 | 2 | Molex | 53047-0510 | CONN HEADER 5POS 1.25MM VERT TIN | 5POS | thru-hole
Click for Instructions on How to Create a BOM (https://www.pcbway.com/blog/PCB_Assembly/How_to_Build_a_BOM__Bill_Of_Materials_.html)
 | S1 | 1 | APEM | MJTB1236B | Tactile Switch |  | THT
 | X4 | 1 | any/open |  | 2x5 Pin shrouded 2,54 mm Header |  | THT
 | C2, C5, C7, C8, C15, C16, C17, C18, C19 | 9 | any/open |  | CAP CER 100nF >=50V X7R | 0805 | SMD
 | R2 | 1 | any/open |  | RES 10,0K OHM 1/8W 1% | 0805 | SMD
 | C1, C4 | 3 | any/open |  | CAP CER 10nF >=50V X7R | 0805 | SMD
 | C3, C13 | 2 | any/open |  | CAP CER 10UF >=16V 10% X7R | 0805 | SMD
 | R1 | 1 | any/open |  | RES 1,0K OHM 1/8W 1% | 0805 | SMD
 | C9, C10 | 2 |  |  | CAP CER 1UF >=25V 10% X7R | 0805 | SMD
 | R3, R4, R8, R9 | 4 | any/open |  | RES 270 OHM 1/8W 1% | 0805 | SMD
 | R5 | 1 | any/open |  | RES 1,0M OHM 1/8W 1% | 0805 | SMD
 | C6 | 1 | any/open |  | CAP CER 4,7UF >=16V 10% X7R | 0805 | SMD
 | X3 | 1 |  |  | AKL 182-04 | AKL182-04
 | DC2 | 1 | murata | CRE1S0505S3C | DC-DC CONVERTER |  | THT
 | IC10 | 1 | FTDI | FT232RL | USB Uart Converter | SSOP28 | SMD
 | DC1 | 1 | MEANWELL | SMU02L-12 | DC-DC CONVERTER |  | THT
 | Q1 | 1 | Infineon | IRF7416 | IRF 7416 | SO-08 | SMD
 | IC7, IC8, IC9 | 3 |  |  |  | SO16 | SMD
 | IC2 | 1 |  |  |  | SOT23 | SMD
 | X2 | 1 |  |  | USB BWM SMD
 | IC1 | 1 |  |  | NCP 1117 ST33T3G | SOT223 | SMD
 | LED1 | 1 |  |  | EVL 19-21SYGC | 0603 | SMD
 | LED2 | 1 |  |  | EVL 19-21SYGC | 0603 | SMD
 | LED3 | 1 |  |  | RND 135-00045 | 0603 | SMD
 | LED4 | 1 |  |  | RND 135-00046 | 0603 | SMD
 | D1 | 1 |  |  |  | SOT23-6 | SMD
 | L10 | 1 |  |  | BLM21PG 300 | 0805 | SMD
 |  | 1 |  |  | BL 2X10W 2,54 | ALLSERIALMM
 |  |  |  |  | AKL 169-04
 |  |  |  |  | MEN 1296.1004
Qty | Value | Device | Package | Parts | Description | OC_REICHELT | OC_FARNELL | PRICE | PRICE_SUM
1 |  | 31-XX | B3F-31XX | S1 | OMRON SWITCH | TASTER 3305B |  | 0.13 € | 0.13 €
1 |  | ML10 | ML10 | X4 | HARTING | WSL 10G |  | 0.08 € | 0.08 €
9 | 100n | C-EUC0805 | C0805 | C2, C5, C7, C8, C15, C16, C17, C18, C19 | CAPACITOR, European symbol | X7R-G0805 100N |  | 0.03 € | 0.27 €
1 | 10k | R-EU_R0805 | R0805 | R2 | RESISTOR, European symbol | SMD-0805 10,0K |  | 0.03 € | 0.03 €
3 | 10n | C-EUC0805 | C0805 | C1, C4 | CAPACITOR, European symbol | X7R-G0805 10N |  | 0.01 € | 0.03 €
2 | 10µ | C-EUC0805 | C0805 | C3, C13 | CAPACITOR, European symbol | KEM X5R0805 10U |  | 0.04 € | 0.08 €
1 | 1k | R-EU_R0805 | R0805 | R1 | RESISTOR, European symbol | SMD-0805 1,00K |  | 0.03 € | 0.03 €
2 | 1µ | C-EUC0805 | C0805 | C9, C10 | CAPACITOR, European symbol | X7R-G0805 1,0/25 |  | 0.04 € | 0.08 €
4 | 270 | R-EU_R0805 | R0805 | R3, R4, R8, R9 | RESISTOR, European symbol | SMD-0805 270 |  | 0.03 € | 0.12 €
1 | 1M | R-EU_R0805 | R0805 | R5 | RESISTOR, European symbol | SMD-0805 1,00M |  | 0.03 € | 0.03 €
1 | 4µ7 | C-EUC0805 | C0805 | C6 | CAPACITOR, European symbol | Y5V 0805 DC 4,7U |  | 0.03 € | 0.03 €
1 | AKL18X-04W | AKL18X-04W | AKL182-04 | X3 | Riacon AKL18X Steckverbinder | AKL 182-04 |  | 0.46 € | 0.46 €
1 | CRE1S0505S3C | NME | NME | DC2 | DC-DC CONVERTER | ROM-0505S |  | 6.30 € | 6.30 €
1 | FT232RL | FT232RL | SSOP28 | IC10 | Source: http://www.ftdichip.com/Documents/DataSheets/DS_FT232R_v104.pdf | FT 232 RL |  | 2.69 € | 2.69 €
1 | IL0512S | NME | NME | DC1 | DC-DC CONVERTER | RI-0512S |  | 6.89 € | 6.89 €
1 | IRF7416 | P-MOSFET-SO8 | SO-08 | Q1 | P-Channel MOSFET | IRF 7416 |  | 0.39 € | 0.39 €
3 | MAX14932 | MAX14932 | SO16 | IC7, IC8, IC9 |  |  | 2528540 | 2.62 € | 7.86 €
1 | MCP1700T-1802E | MCP170X | SOT23 | IC2 |  |  | 1296591 | 0.32 € | 0.32 €
1 | MINI-USB-32005-201 | MINI-USB-32005-201 | 32005-201 | X2 | MINI USB-B Conector | USB BWM SMD |  | 0.24 € | 0.24 €
1 | NCP1117-33ST | NCP1117-33ST | SOT223 | IC1 |  | NCP 1117 ST33T3G |  | 0.24 € | 0.24 €
1 | PWR | LEDCHIPLED_0603 | CHIPLED_0603 | LED1 | LED | EVL 19-21SYGC |  | 0.06 € | 0.06 €
1 | RX | LEDCHIPLED_0603 | CHIPLED_0603 | LED2 | LED | EVL 19-21SYGC |  | 0.06 € | 0.06 €
1 | TX | LEDCHIPLED_0603 | CHIPLED_0603 | LED3 | LED | RND 135-00045 |  | 0.05 € | 0.05 €
1 | TXEN | LEDCHIPLED_0603 | CHIPLED_0603 | LED4 | LED | RND 135-00046 |  | 0.05 € | 0.05 €
1 | USBLC6-2 | WE-TVS_82400102 | WE-TVS_SOT23-6L | D1 | TVS Diode Array WE-TVS, High Speed Series |  | 1295310 | 0.28 € | 0.28 €
1 | WE-CBF_0805 | WE-CBF_0805 | 805 | L10 | SMD EMI Suppression Ferrite Beads WE-CBF | BLM21PG 300 |  | 0.04 € | 0.04 €
1 | ALLSERIALMM | ALLSERIALMM | ALLSERIALMM |  |  | BL 2X10W 2,54 |  | 0.27 € | 0.27 €
1 |  |  |  |  | Connector | AKL 169-04 |  | 0.88 € | 0.88 €
1 |  |  |  |  | Mentor | MEN 1296.1004 |  | 0.83 € | 0.83 €

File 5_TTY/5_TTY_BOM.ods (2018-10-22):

Qty | Value | Device | Package | Parts | Description | OC_REICHELT | PRICE | PRICE_SUM
1 |  |  |  | X1 | PIN HEADER | SL 2X10W 2,54 | 0,15 € | 0,15 €
1 |  | MA08-2W | MA08-2W | X3 |  | MPE 088-2-006 | 0,17 € | 0,17 €
1 | 100 | R-EU_R0805 | R0805 | R19 | RESISTOR, European symbol | SMD-0805 100 | 0,03 € | 0,03 €
2 | 10k | R-EU_R0805 | R0805 | R10, R11 | RESISTOR, European symbol | SMD-0805 10,0K | 0,13 € | 0,25 €
2 | 10k | R-EU_R0805 | R0805 | R15, R17 | RESISTOR, European symbol | SMD-0805 10,0K | 0,13 € | 0,25 €
2 | 15R | R-EU_R0805 | R0805 | R1, R2 | RESISTOR, European symbol | SMD-0805 15,0 | 0,03 € | 0,05 €
1 | 180k | R-EU_R0805 | R0805 | R18 | RESISTOR, European symbol | SMD-0805 180K | 0,03 € | 0,03 €
1 | 3,3V | ZENER-DIODESOT23 | SOT23 | D1 | Z-Diode | SMD ZD 3,3 | 0,03 € | 0,03 €
1 | 33R | R-EU_R0805 | R0805 | R16 | RESISTOR, European symbol | SMD-0805 33,0 | 0,03 € | 0,03 €
2 | 4N25 | 4N35 | DIL06 | OK1, OK2 | MOTOROLA OPTO COUPLER | 4N 25 | 0,42 € | 0,84 €
1 | 4k7 | R-EU_R0805 | R0805 | R20 | RESISTOR, European symbol | SMD-0805 4,70K | 0,03 € | 0,03 €
1 | 5V | ZENER-DIODESOT23 | SOT23 | D2 | Z-Diode | SMD ZD 5,1 | 0,03 € | 0,03 €
1 | 68 | R-EU_R0805 | R0805 | R13 | RESISTOR, European symbol | SMD-0805 68,0 | 0,03 € | 0,03 €
3 | 68 | R-EU_R0805 | R0805 | R3, R4, R14 | RESISTOR, European symbol | SMD-0805 68,0 | 0,03 € | 0,08 €
1 | 82 | R-EU_R0805 | R0805 | R12 | RESISTOR, European symbol | SMD-0805 82,0 | 0,03 € | 0,03 €
1 | AKL18X-08W | AKL18X-08W | AKL182-08 | X2 | Riacon AKL18X Steckverbinder | AKL 182-08 |  | 0,00 €
1 |  |  |  |  | Riacon Anschlussklemme | AKL 169-08 | 1,39 € | 1,39 €
1 | BC847 | BC847 | SOT23 | T4 | NPN TRANSISTOR | BC 847CW SMD | 0,03 € | 0,03 €
5 | BC857C | BC857CSMD | SOT23-BEC | Q2, Q3, Q4, Q5, Q6 | PNP Transistror | BC 857 NXP | 0,08 € | 0,42 €
1 | gn | LEDCHIPLED_0603 | CHIPLED_0603 | LED6 | LED | LED EL 0603 GR2 | 0,13 € | 0,13 €
1 | rd | LEDCHIPLED_0603 | CHIPLED_0603 | LED5 | LED | LED EL 0603 RT | 0,07 € | 0,07 €
1 |  |  |  |  |  | MEN 1296.2012 | 0,49 € | 0,49 €
 |  |  |  |  | Jumper | MPE 149-4-002-F0 | 0,05 € | 0,00 €
 |  |  |  |  |  |  |  | 4,51 €

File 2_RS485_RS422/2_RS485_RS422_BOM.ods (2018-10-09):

Qty | Value | Device | Package | Parts | Description | MF | MPN | OC_REICHELT | OC_FARNELL | PRICE | PRICE_SUM
4 | 100n | C-EUC0805 | C0805 | C1, C2, C3, C4 | CAPACITOR, European symbol |  |  | X7R-G0805 100N |  | 0,03 € | 0,10 €
4 | 120 | R-EU_R0805 | R0805 | R5, R22, R30, R31 | RESISTOR, European symbol |  |  | SMD-0805 120 |  | 0,03 € | 0,10 €
1 | 4k7 | R-EU_R0805 | R0805 | R1 | RESISTOR, European symbol |  |  | SMD-0805 4,70K |  | 0,03 € | 0,03 €
1 | 74HCT02D | 74HCT02D | SO14 | IC1 | Quad 2-input NOR gate |  |  | 74HC 02D NXP |  | 0,18 € | 0,18 €
1 | AKL18X-10W | AKL18X-10W | AKL182-10 | X2 | Riacon AKL18X Steckverbinder |  |  | AKL 182-10 |  | 0,83 € | 0,83 €
1 | ALLSERIALD | ALLSERIALD | DAUGHTER-THT | X1 |  |  |  | SL 2X10W 2,54 |  | 0,15 € | 0,15 €
1 | MA05-2W | MA05-2W | MA05-2W | SV1 |  |  |  | MPE 088-2-010 |  | 0,18 € | 0,18 €
2 | MAX485CSA | MAX481CSA | SO08 | IC2, IC3 | RS485 TRANSEIVER | MAXIM | MAX481CSA | MAX 485 CSA |  | 1,13 € | 2,27 €
1 | MAX489CSD | MAX489CSD | SO14 | IC4 | RS485 TRANSEIVER | MAXIM | MAX489CSD | MAX 489 CSD |  | 2,73 € | 2,73 €
1 |  |  |  |  | Connector |  |  | AKL169-08 |  | 1,39 € | 1,39 €
4 |  |  |  |  | Jumper |  |  | MPE 149-4-002-F4 |  | 0,05 € | 0,20 €
 |  |  |  |  |  |  |  |  |  |  | 8,16 €

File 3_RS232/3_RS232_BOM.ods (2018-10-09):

Qty | Value | Device | Package | Parts | Description | OC_REICHELT | OC_FARNELL | PRICE | PRICE_SUM
1 |  | M09HP | M09HP | X4 | SUB-D | D-SUB ST 09EU |  | 0,34 € | 0,34 €
5 | 100n | C-EUC0805 | C0805 | C40, C41, C44, C45, C48 | CAPACITOR, European symbol | X7R-G0805 100N |  | 0,03 € | 0,13 €
1 | ALLSERIALD | ALLSERIALD | DAUGHTER-THT | X9 |  | SL 2X10W 2,54 |  | 0,15 € | 0,15 €
1 | MAX211ECWI | MAX211ECWI | SO28L | IC5 | RS232 TRANSCEIVER |  | 2511832 | 4,34 € | 4,34 €
 |  |  |  |  |  |  |  |  | 4,95 €

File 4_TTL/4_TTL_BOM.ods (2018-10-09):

Qty | Value | Device | Package | Parts | Description | OC_REICHELT | OC_FARNELL | PRICE | PRICE SUM
2 | 1µ | C-EUC0805K | C0805K | C1, C2 | CAPACITOR, European symbol | X7R-G0805 1,0/25 |  | 0,04 € | 0,08 €
1 | AKL18X-10W | AKL18X-10W | AKL182-10 | X2 | Riacon AKL18X Steckverbinder | AKL 182-10 |  | 0,83 € | 0,83 €
1 | ALLSERIALSLAVE | ALLSERIALSLAVE | DAUGHTER-THT | X1 |  | SL 2X10W 2,54 |  | 0,15 € | 0,15 €
1 | MCP1700T-2502E | MCP170X | SOT23 | IC1 |  |  | 1605553 | 0,32 € | 0,32 €
1 | X3 | MA04-2W | MA04-2W | SV1 | PIN HEADER | MPE 088-2-008 |  | 0,23 € | 0,23 €
1 |  |  |  |  | Connector | AKL 169-10 |  | 1,67 € | 1,67 €
1 |  |  |  |  | Jumper | MPE 149-4-002-F4 |  | 0,05 € | 0,05 €
 |  |  |  |  |  |  |  |  | 3,34 €

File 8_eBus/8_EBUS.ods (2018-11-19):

Qty | Value | Device | Package | Parts | Description | OC_REICHELT | OC_FARNELL | PRICE | PRICE_SUM
4 |  | DIODE-SOD80C | SOD80C | D1, D2, D3, D4 | DIODE | 1N 4148 SMD |  | 0,02 € | 0,07 €
1 |  | LEDCHIPLED_0805 | CHIPLED_0805 | LED1 | LED | KBT KP-2012MGC |  | 0,27 € | 0,27 €
2 | 100n | C-EUC0805 | C0805 | C1, C2 | CAPACITOR, European symbol | X7R-G0805 100N |  | 0,03 € | 0,06 €
2 | 10k | R-EU_R0805 | R0805 | R1, R2 | RESISTOR, European symbol | SMD-0805 10,0K |  | 0,03 € | 0,06 €
1 | 12k | R-EU_R0805 | R0805 | R3 | RESISTOR, European symbol | SMD-0805 12,0K |  | 0,03 € | 0,03 €
1 | 270 | R-EU_R0805 | R0805 | R5 | RESISTOR, European symbol | SMD-0805 270 |  | 0,03 € | 0,03 €
1 | 47k | R-EU_R0805 | R0805 | R4 | RESISTOR, European symbol | SMD-0805 47,0K |  | 0,03 € | 0,03 €
1 | 4k7 | R-EU_R0805 | R0805 | R6 | RESISTOR, European symbol | SMD-0805 4,70K |  | 0,03 € | 0,03 €
1 | AKL18X-02W | AKL18X-02W | AKL182-02 | X1 | Riacon AKL18X Steckverbinder | AKL 182-02 |  | 0,23 € | 0,23 €
1 | ALLSERIALSLAVE | ALLSERIALSLAVE | DAUGHTER-THT | X2 |  | SL 2X10W 2,54 |  | 0,15 € | 0,15 €
1 | BC817 | BC817-16LT1SMD | SOT23-BEC | Q1 | NPN Transistor | BC 817 NXP |  | 0,03 € | 0,03 €
1 | MCP6542 | LM393D | SO08 | IC1 | COMPARATOR | MCP 6542-I/SN |  | 0,35 € | 0,35 €
1 | TCMC27 | ZENER-DIODESOD80C | SOD80C | D6 | Z-Diode | SMD ZF 27 |  | 0,03 € | 0,03 €
1 | TCMC7V5 | ZENER-DIODESOD80C | SOD80C | D5 | Z-Diode | SMD ZF 7,5 |  | 0,03 € | 0,03 €
1 |  |  |  |  | Connector | AKL 169-02 |  | 0,43 € | 0,43 €
1 |  |  |  |  | light duct | MEN 12711000 |  | 0,50 € | 0,50 €

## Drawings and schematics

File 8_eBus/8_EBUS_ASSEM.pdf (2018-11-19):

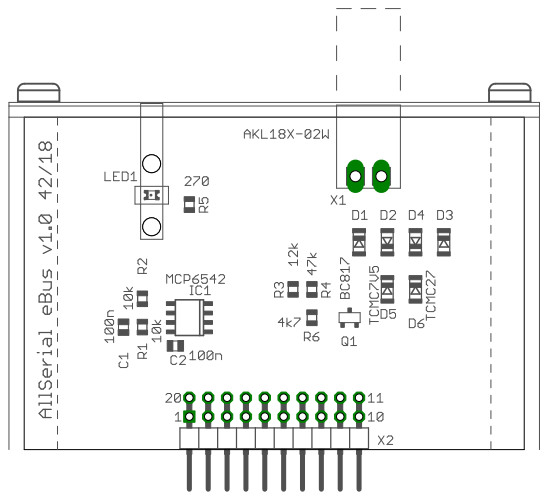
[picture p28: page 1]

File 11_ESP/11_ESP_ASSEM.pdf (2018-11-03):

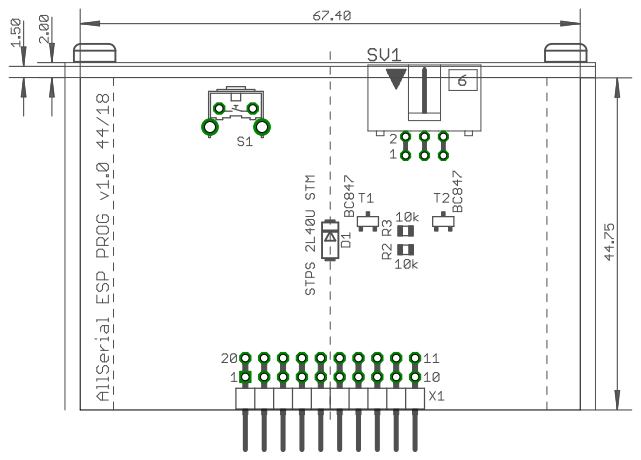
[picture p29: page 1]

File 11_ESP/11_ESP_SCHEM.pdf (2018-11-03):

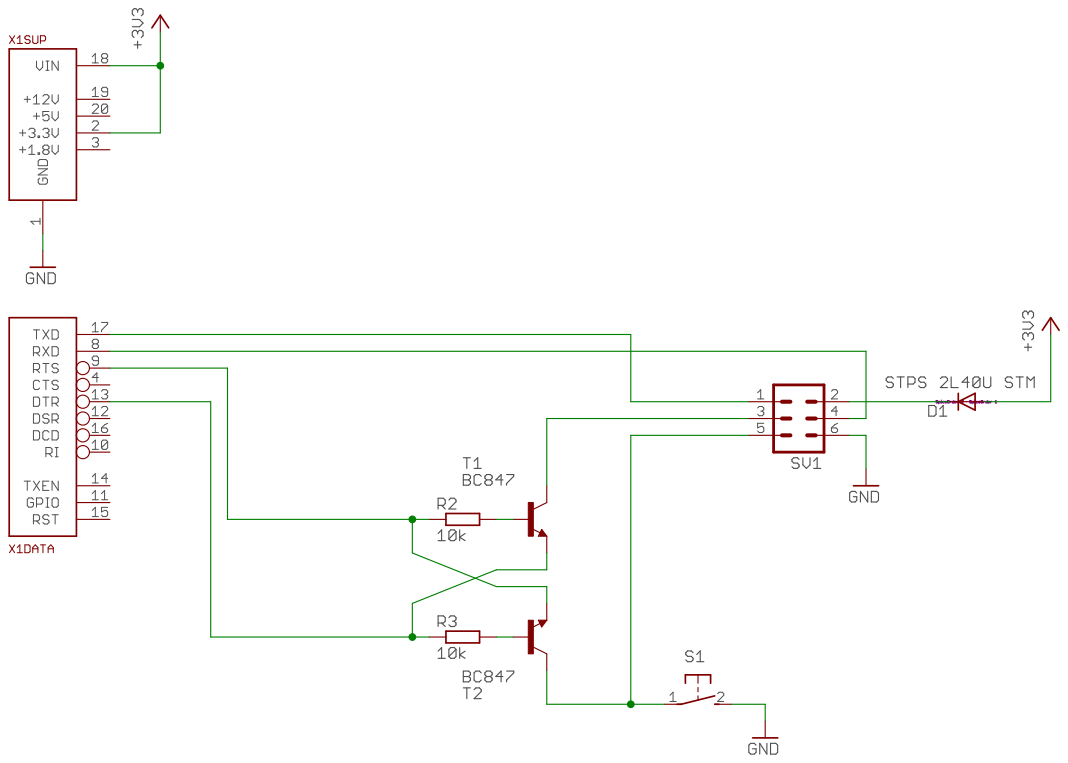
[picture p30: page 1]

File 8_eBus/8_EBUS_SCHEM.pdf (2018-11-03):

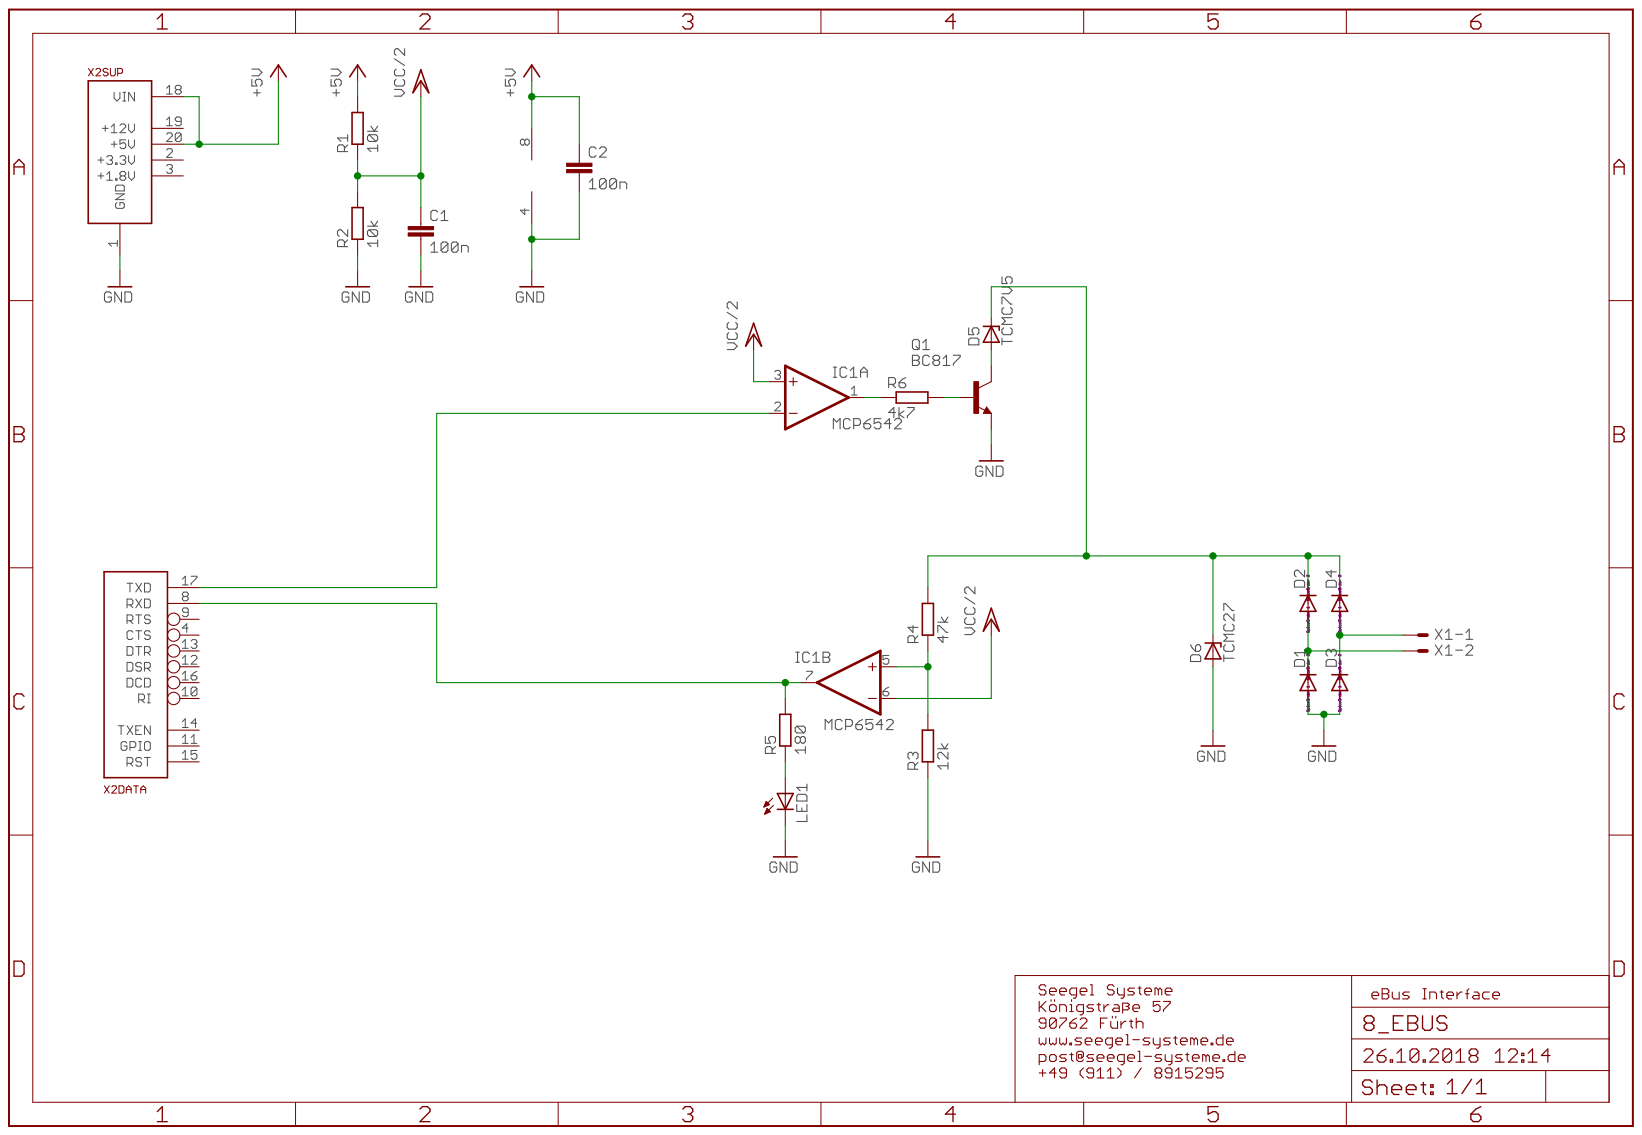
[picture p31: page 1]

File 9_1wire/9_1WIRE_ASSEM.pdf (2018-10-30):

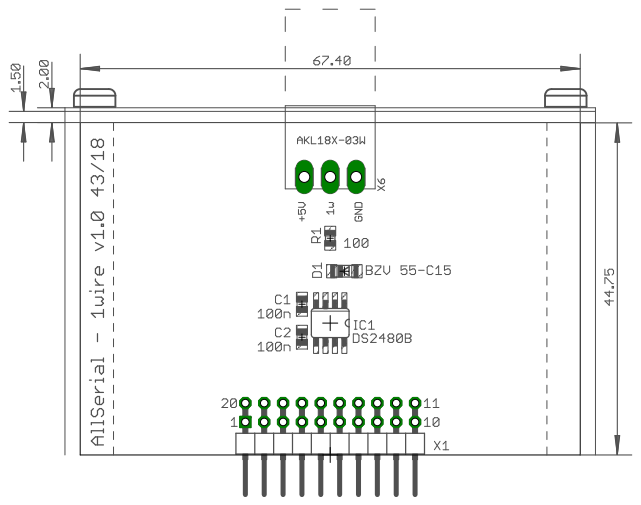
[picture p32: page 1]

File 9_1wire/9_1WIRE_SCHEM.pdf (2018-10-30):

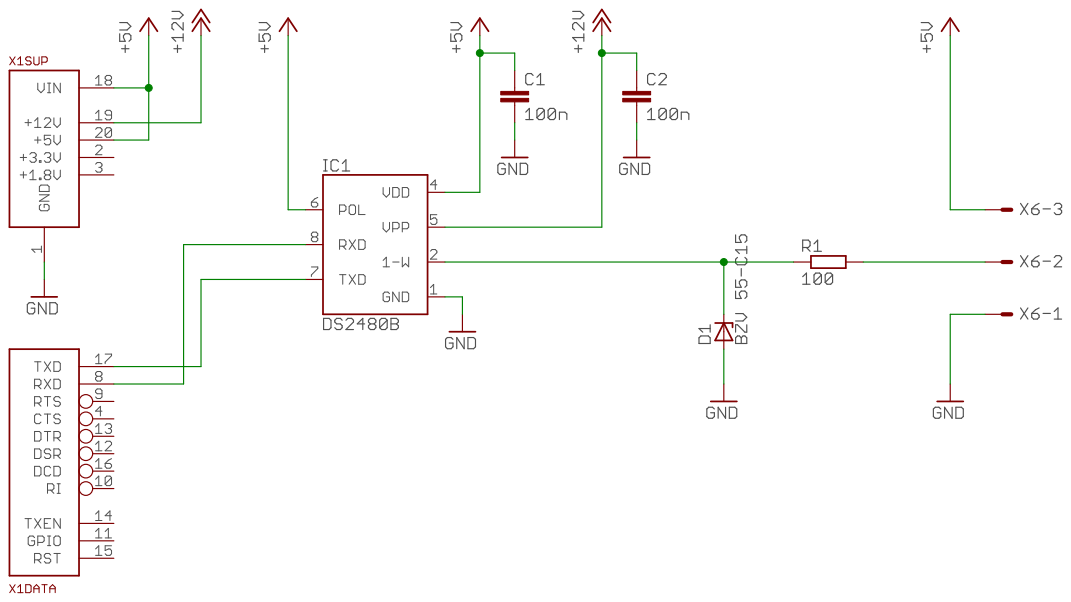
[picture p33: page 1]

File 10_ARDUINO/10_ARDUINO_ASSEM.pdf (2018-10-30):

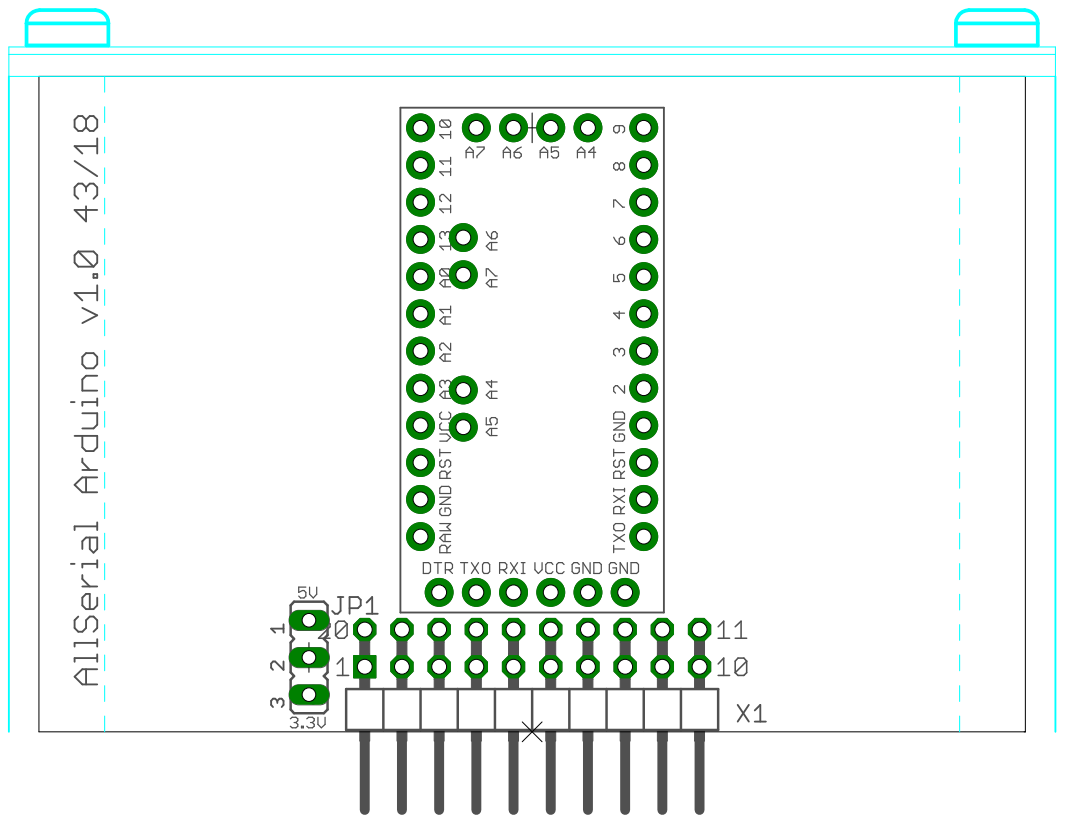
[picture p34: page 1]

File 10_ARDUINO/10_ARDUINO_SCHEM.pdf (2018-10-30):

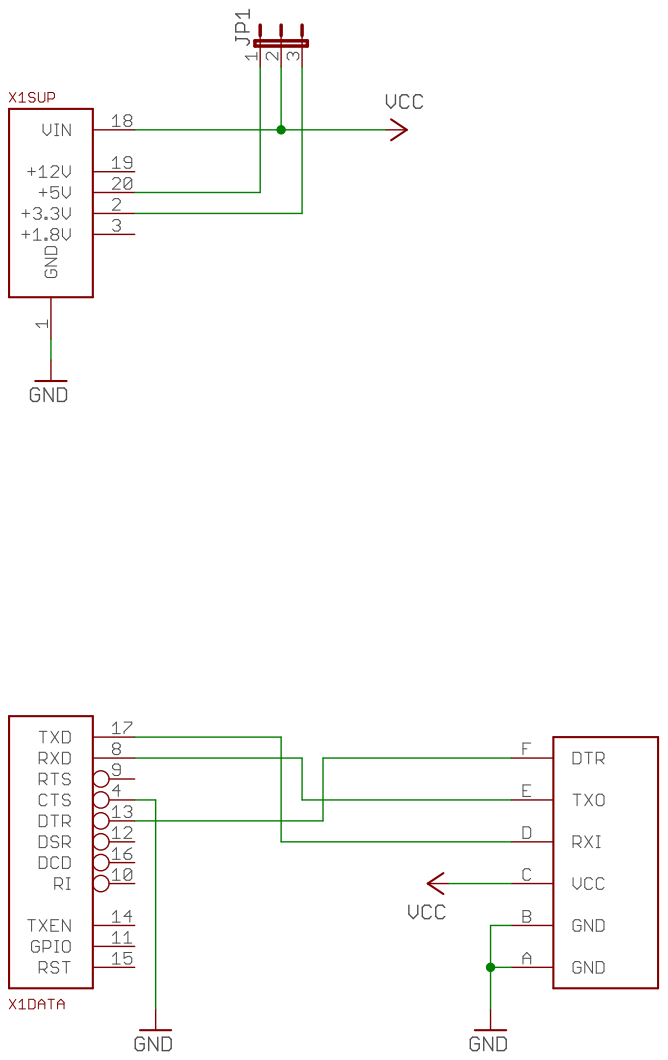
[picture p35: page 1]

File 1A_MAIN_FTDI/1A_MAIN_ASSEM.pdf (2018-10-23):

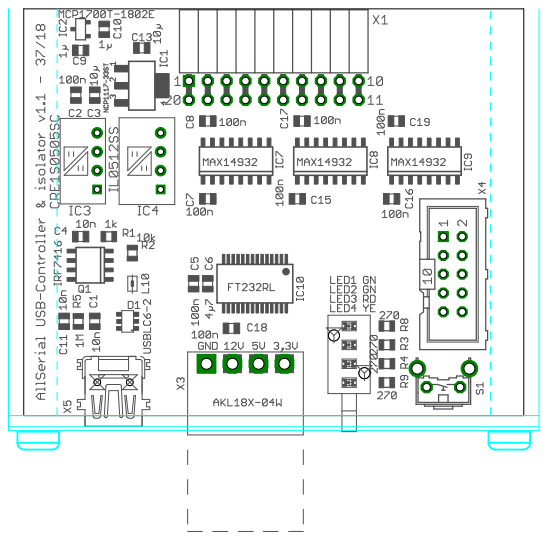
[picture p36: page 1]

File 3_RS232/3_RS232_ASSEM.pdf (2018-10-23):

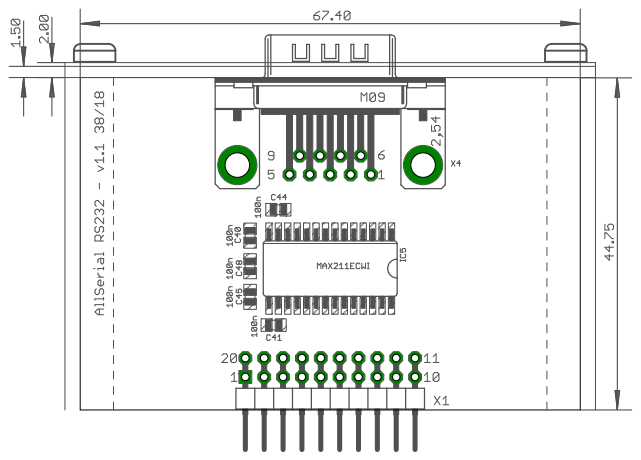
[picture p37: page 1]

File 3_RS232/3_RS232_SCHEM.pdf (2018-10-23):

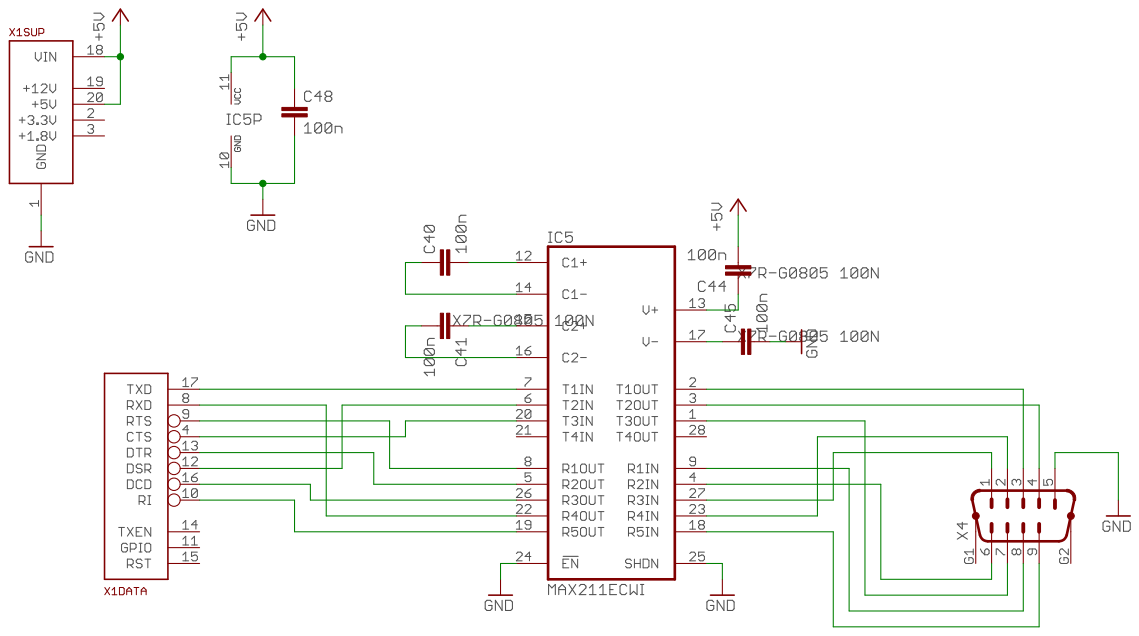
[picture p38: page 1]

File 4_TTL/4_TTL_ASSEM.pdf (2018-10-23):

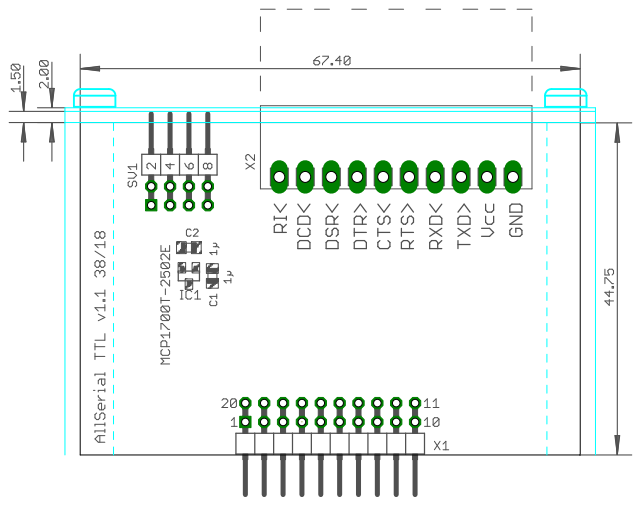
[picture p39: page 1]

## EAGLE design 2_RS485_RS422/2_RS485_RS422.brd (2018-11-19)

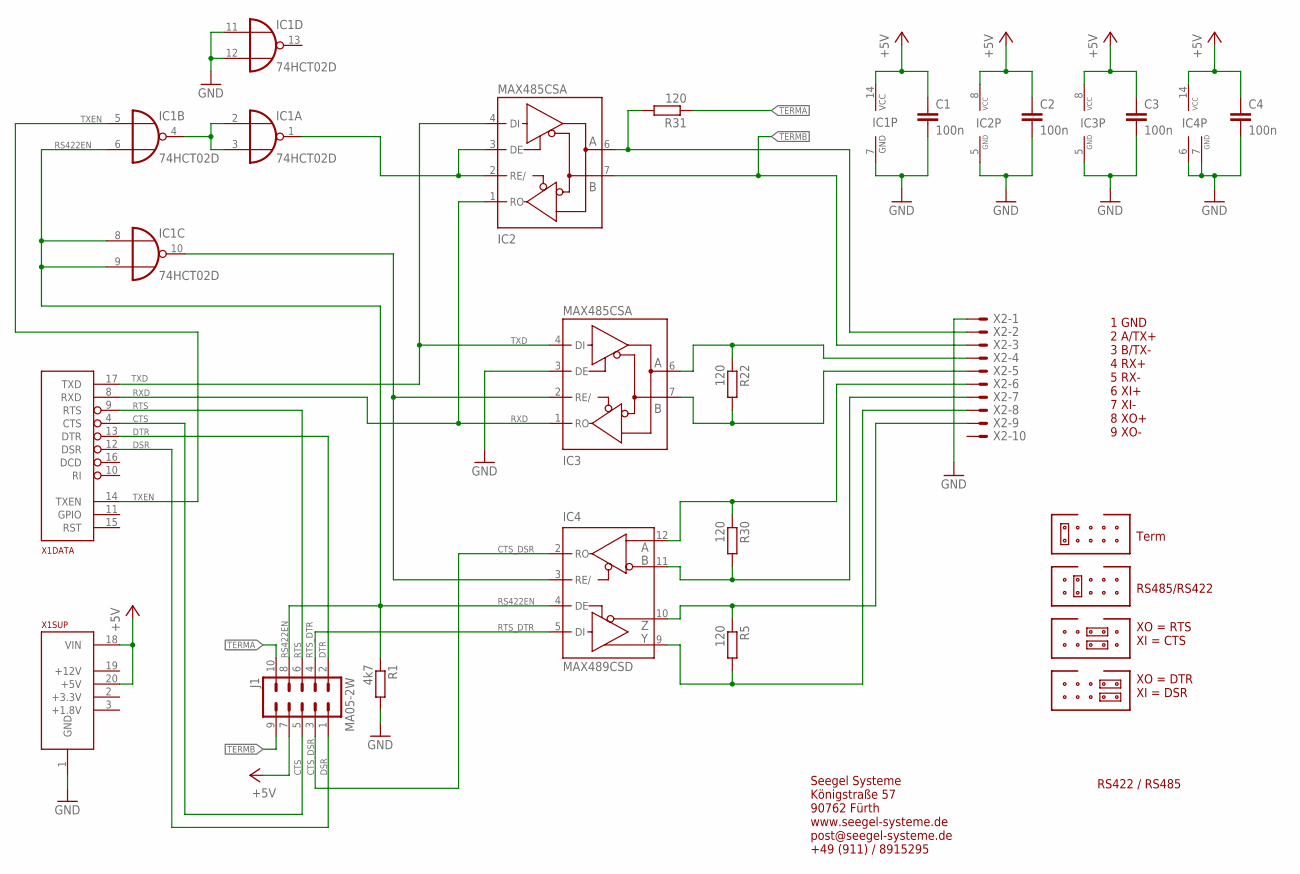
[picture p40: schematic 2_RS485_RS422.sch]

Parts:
C1, C2, C3, C4: 100n; C0805
IC1: 74HCT02D; SO14
IC2, IC3: MAX485CSA; SO08
IC4: MAX489CSD; SO14
J1: MA05-2W
R1: 4k7; R0805
R5, R22, R30, R31: 120; R0805
X1: ALLSERIALSLAVE; DAUGHTER-THT
X2: AKL18X-10W; AKL182-10

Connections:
+5V: C1.1, C2.1, C3.1, C4.1, IC1.14 (VCC), IC2.8 (VCC), IC3.8 (VCC), IC4.14 (VCC), J1.7, X1.18 (VIN), X1.20 (+5V)
CTS: J1.5, X1.4 (CTS)
CTS_DSR: IC4.2 (RO), J1.3
DSR: J1.1, X1.12 (DSR)
DTR: J1.2, X1.13 (DTR)
GND: C1.2, C2.2, C3.2, C4.2, IC1.7 (GND), IC1.11 (I0), IC1.12 (I1), IC2.5 (GND), IC3.3 (DE), IC3.5 (GND), IC4.6 (GND), IC4.7 (GND), R1.2, X1.1 (GND), X2.P$1
unnamed: IC4.11 (B), R30.2, X2.P$7
unnamed: IC4.10 (Z), R5.1, X2.P$9
unnamed: IC2.6 (A), R31.2, X2.P$2
unnamed: IC4.9 (Y), R5.2, X2.P$8
unnamed: IC4.12 (A), R30.1, X2.P$6
unnamed: IC3.7 (B), R22.2, X2.P$5
unnamed: IC3.6 (A), R22.1, X2.P$4
unnamed: IC1.2 (I0), IC1.3 (I1), IC1.4 (O)
unnamed: IC1.1 (O), IC2.2 (RE/), IC2.3 (DE)
unnamed: IC1.10 (O), IC3.2 (RE/), IC4.3 (RE/)
RS422EN: IC1.6 (I1), IC1.8 (I0), IC1.9 (I1), IC4.4 (DE), J1.8, R1.1
RTS: J1.6, X1.9 (RTS)
RTS_DTR: IC4.5 (DI), J1.4
RXD: IC2.1 (RO), IC3.1 (RO), X1.8 (RXD)
TERMA: J1.10, R31.1
TERMB: IC2.7 (B), J1.9, X2.P$3
TXD: IC2.4 (DI), IC3.4 (DI), X1.17 (TXD)
TXEN: IC1.5 (I0), X1.14 (TXEN)

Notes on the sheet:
Seegel Systeme Königstraße 57 90762 Fürth www.seegel-systeme.de post@seegel-systeme.de +49 (911) / 8915295
RS422 / RS485
Term
RS485/RS422
XO = RTS XI = CTS
XO = DTR XI = DSR
1 GND 2 A/TX+ 3 B/TX- 4 RX+ 5 RX- 6 XI+ 7 XI- 8 XO+ 9 XO-

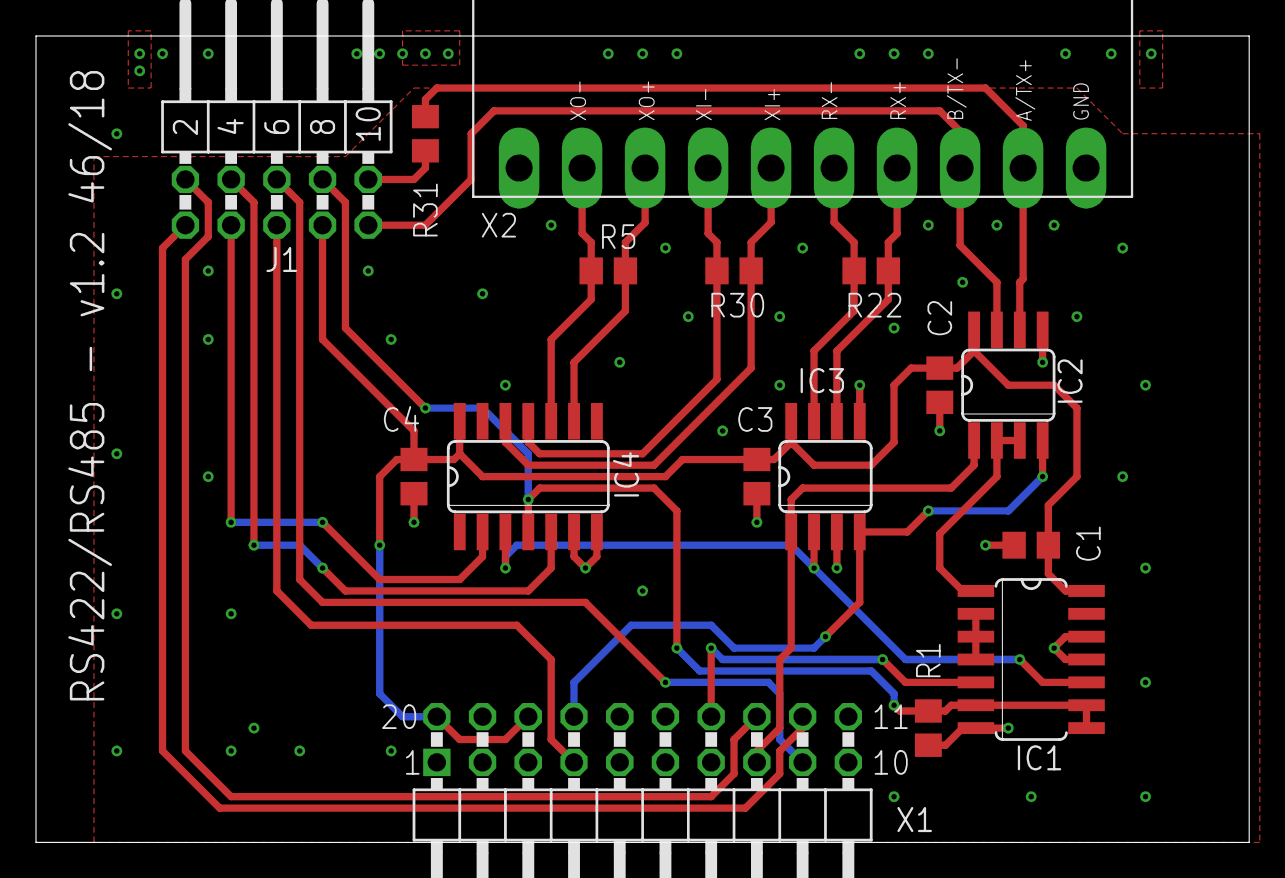
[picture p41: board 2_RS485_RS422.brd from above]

Board: 2 copper layers, 67.4 x 44.8 mm, 18 parts (0 on the bottom side), 24 nets.

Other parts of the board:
U$4, U$5: JUMPER

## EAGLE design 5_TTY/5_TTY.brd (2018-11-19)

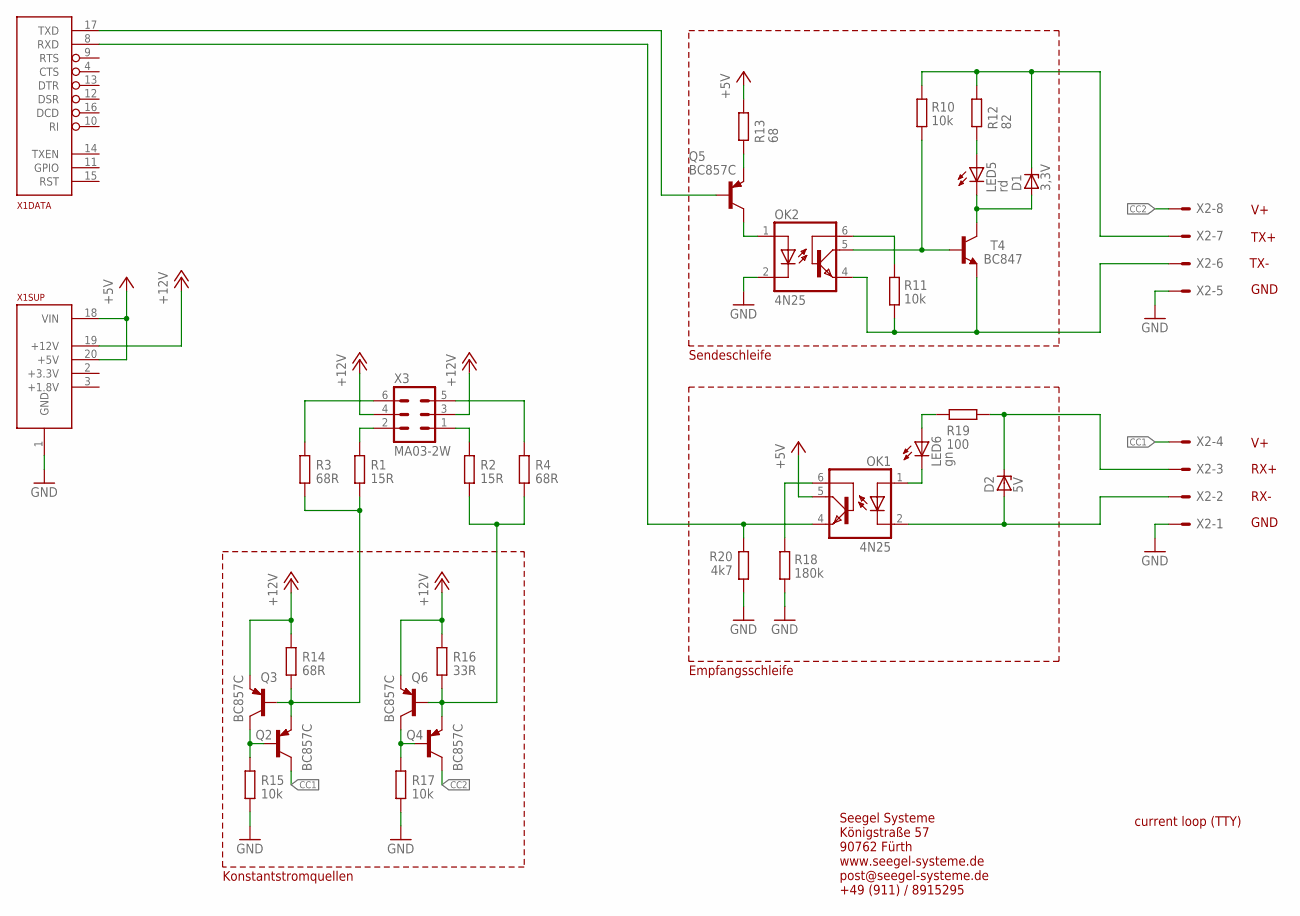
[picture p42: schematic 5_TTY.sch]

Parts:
D1: 3,3V; SOT23
D2: 5V; SOT23
LED5: rd; CHIPLED_0603
LED6: gn; CHIPLED_0603
OK1, OK2: 4N25; DIL06; FARNELL 1612454
Q2, Q3, Q4, Q5, Q6: BC857C; SOT23-BEC; FARNELL 8734771
R1, R2: 15R; R0805; FARNELL 2498090
R3, R4, R14: 68R; R0805; FARNELL 2498090
R10, R11: 10k; R0805; FARNELL 2498051
R12: 82; R0805; FARNELL 2498057
R13: 68; R0805; FARNELL 2498057
R15, R17: 10k; R0805; FARNELL 2502672
R16: 33R; R0805; FARNELL 2498090
R18: 180k; R0805; FARNELL 2498051
R19: 100; R0805; FARNELL 2498057
R20: 4k7; R0805; FARNELL 2498050
T4: BC847; SOT23; FARNELL 1081230
X1: ALLSERIALSLAVE; DAUGHTER-THT
X2: AKL18X-08W; AKL182-08
X3: MA03-2W

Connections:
+5V: OK1.5 (COL), R13.1, X1.18 (VIN), X1.20 (+5V)
+12V: Q3.E, Q6.E, R14.1, R16.1, X1.19 (+12V), X3.3, X3.4
CC1: Q2.C, X2.P$4
CC2: Q4.C, X2.P$8
GND: OK2.2 (C), R15.1, R17.1, R18.2, R20.1, X1.1 (GND), X2.P$1, X2.P$5
unnamed: OK1.6 (BAS), R18.1
unnamed: R1.1, X3.2
unnamed: R2.1, X3.1
unnamed: OK2.4 (EMI), R11.2, T4.2 (E), X2.P$6
unnamed: R3.1, X3.6
unnamed: R4.1, X3.5
unnamed: D2.3 (C), R19.1, X2.P$3
unnamed: D2.1 (A), OK1.2 (C), X2.P$2
unnamed: Q4.B, Q6.C, R17.2
unnamed: OK1.4 (EMI), R20.2, X1.8 (RXD)
unnamed: Q4.E, Q6.B, R2.2, R4.2, R16.2
unnamed: OK2.6 (BAS), R11.1
unnamed: OK2.5 (COL), R10.2, T4.1 (B)
unnamed: D1.1 (A), LED5.C, T4.3 (C)
unnamed: Q2.B, Q3.C, R15.2
unnamed: LED5.A, R12.2
unnamed: Q2.E, Q3.B, R1.2, R3.2, R14.2
unnamed: OK2.1 (A), Q5.C
unnamed: Q5.E, R13.2
unnamed: LED6.C, OK1.1 (A)
unnamed: LED6.A, R19.2
unnamed: Q5.B, X1.17 (TXD)
TXP: D1.3 (C), R10.1, R12.1, X2.P$7

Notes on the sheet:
current loop (TTY)
Konstantstromquellen
Empfangsschleife
Sendeschleife
Seegel Systeme Königstraße 57 90762 Fürth www.seegel-systeme.de post@seegel-systeme.de +49 (911) / 8915295
TX+
TX-
GND
RX+
RX-

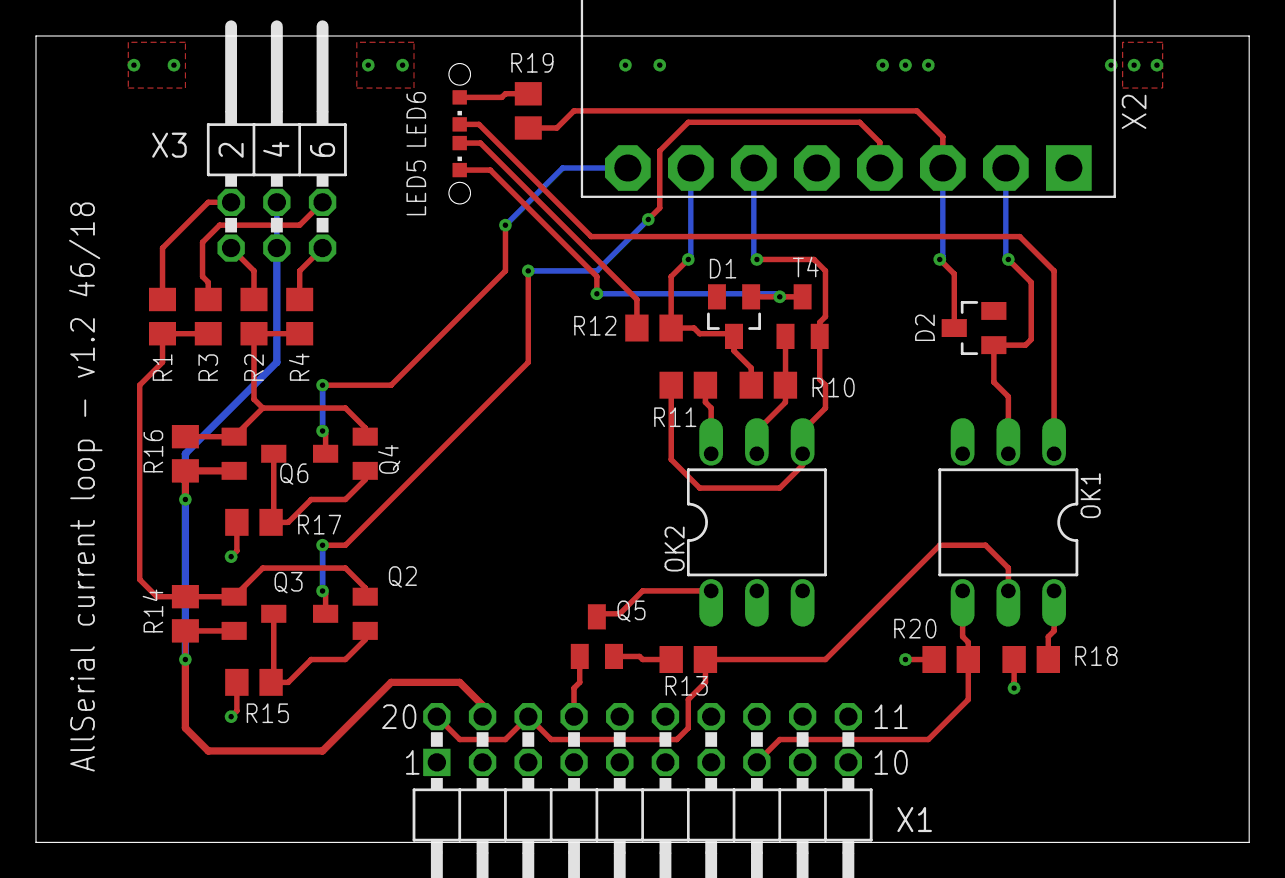
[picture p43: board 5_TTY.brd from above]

Board: 2 copper layers, 67.4 x 44.8 mm, 31 parts (0 on the bottom side), 28 nets.

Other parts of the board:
U$7: 1296.2012

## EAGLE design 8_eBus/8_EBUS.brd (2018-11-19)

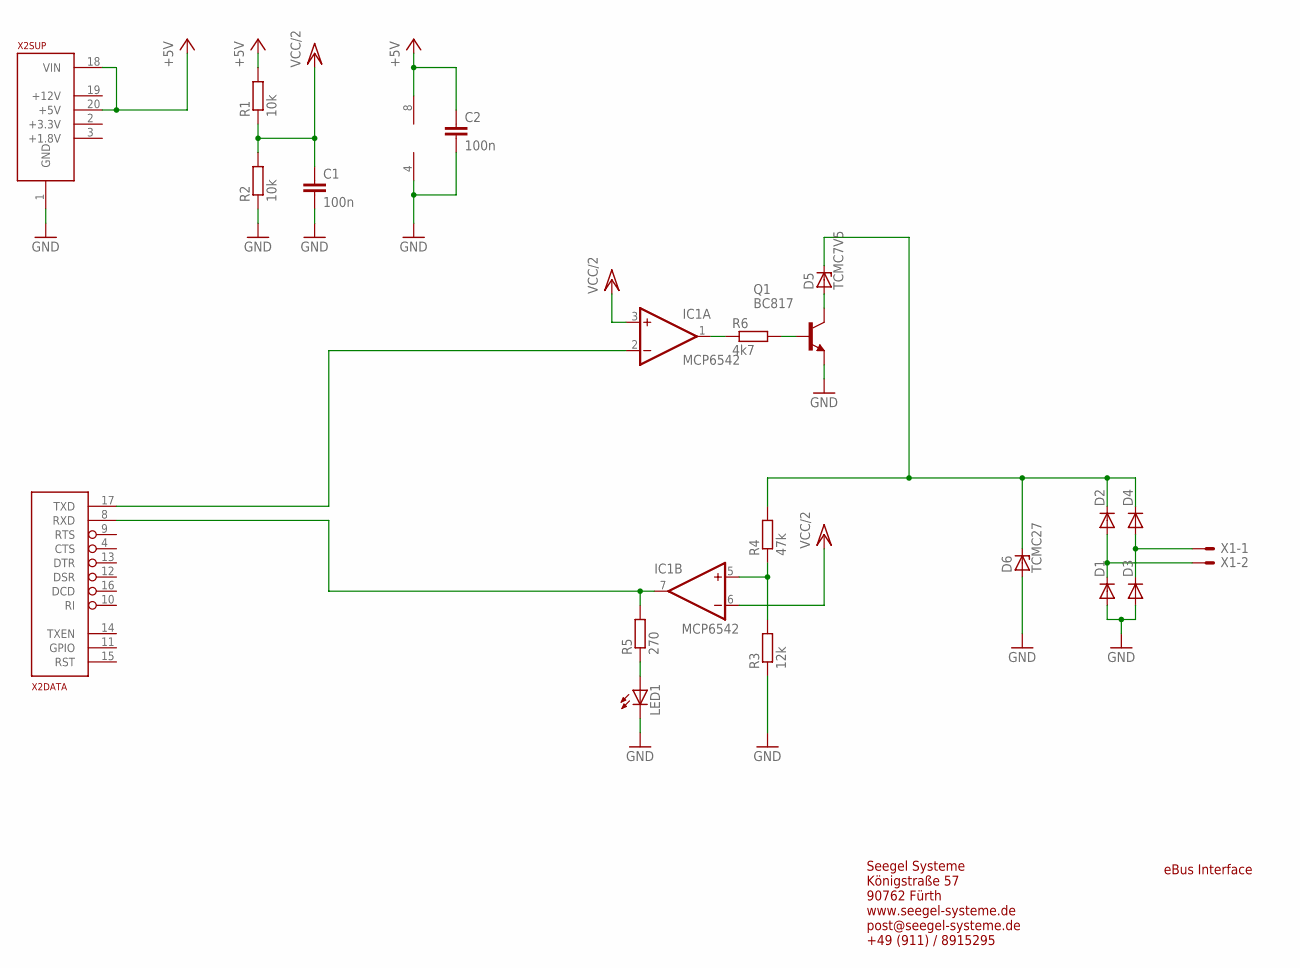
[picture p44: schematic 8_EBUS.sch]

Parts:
C1, C2: 100n; C0805
D1, D2, D3, D4: DIODE-SOD80C; SOD80C
D5: TCMC7V5; SOD80C
D6: TCMC27; SOD80C
IC1: MCP6542; SO08
LED1: LEDCHIPLED_0805; CHIPLED_0805
Q1: BC817; SOT23-BEC
R1, R2: 10k; R0805
R3: 12k; R0805
R4: 47k; R0805
R5: 270; R0805
R6: 4k7; R0805
X1: AKL18X-02W; AKL182-02
X2: ALLSERIALSLAVE; DAUGHTER-THT

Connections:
+5V: C2.1, IC1.8 (V+), R1.2, X2.18 (VIN), X2.20 (+5V)
GND: C1.2, C2.2, D1.A, D3.A, D6.A, IC1.4 (V-), LED1.C, Q1.E, R2.1, R3.1, X2.1 (GND)
unnamed: D2.C, D4.C, D5.C, D6.C, R4.2
unnamed: D3.C, D4.A, X1.P$1
unnamed: D1.C, D2.A, X1.P$2
unnamed: Q1.B, R6.2
unnamed: D5.A, Q1.C
unnamed: IC1.5 (+IN), R3.2, R4.1
unnamed: IC1.2 (-IN), X2.17 (TXD)
unnamed: IC1.1 (OUT), R6.1
unnamed: LED1.A, R5.1
unnamed: IC1.7 (OUT), R5.2, X2.8 (RXD)
VCC/2: C1.1, IC1.3 (+IN), IC1.6 (-IN), R1.1, R2.2

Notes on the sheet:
eBus Interface
Seegel Systeme Königstraße 57 90762 Fürth www.seegel-systeme.de post@seegel-systeme.de +49 (911) / 8915295

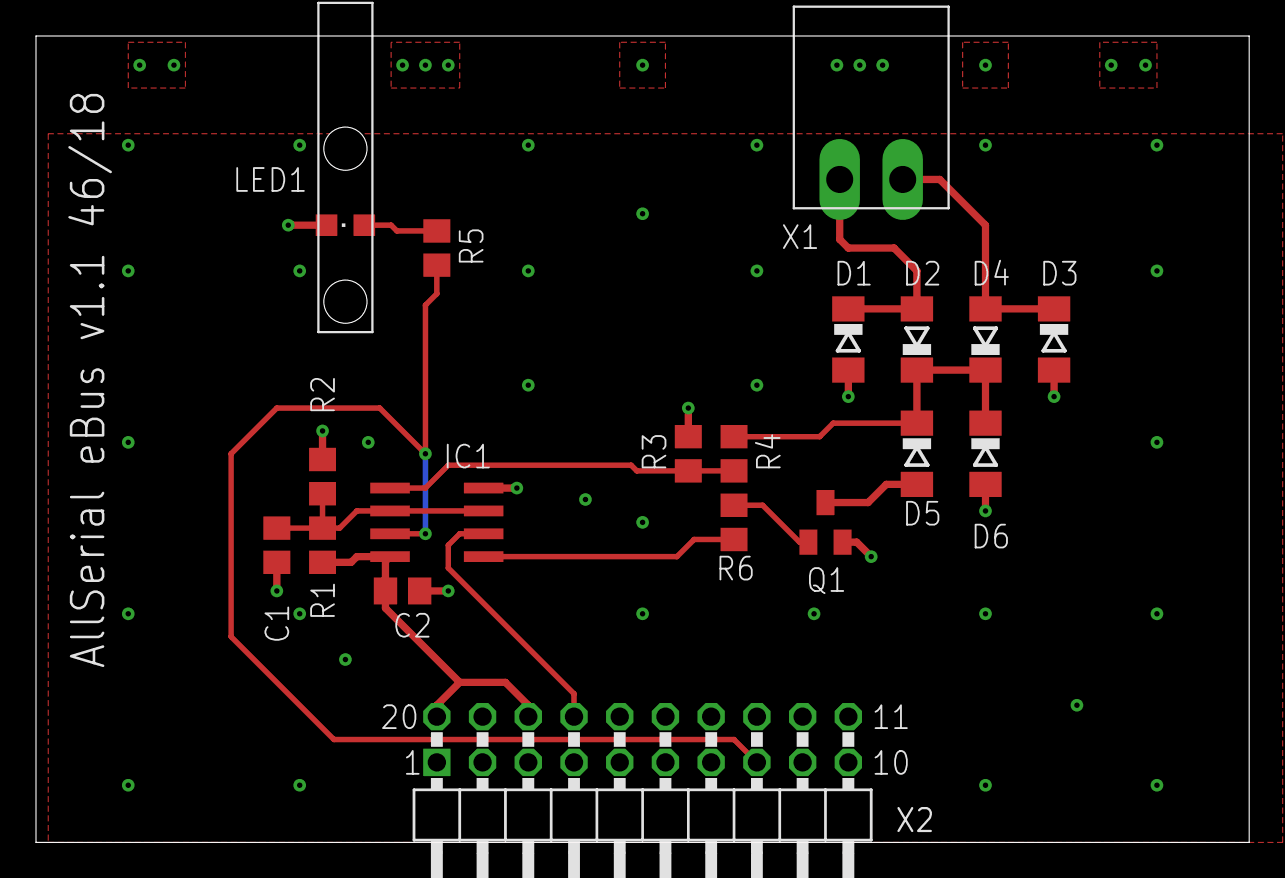
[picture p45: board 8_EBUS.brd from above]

Board: 2 copper layers, 67.4 x 44.8 mm, 20 parts (0 on the bottom side), 13 nets.

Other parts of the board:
U$1: 1271.1000

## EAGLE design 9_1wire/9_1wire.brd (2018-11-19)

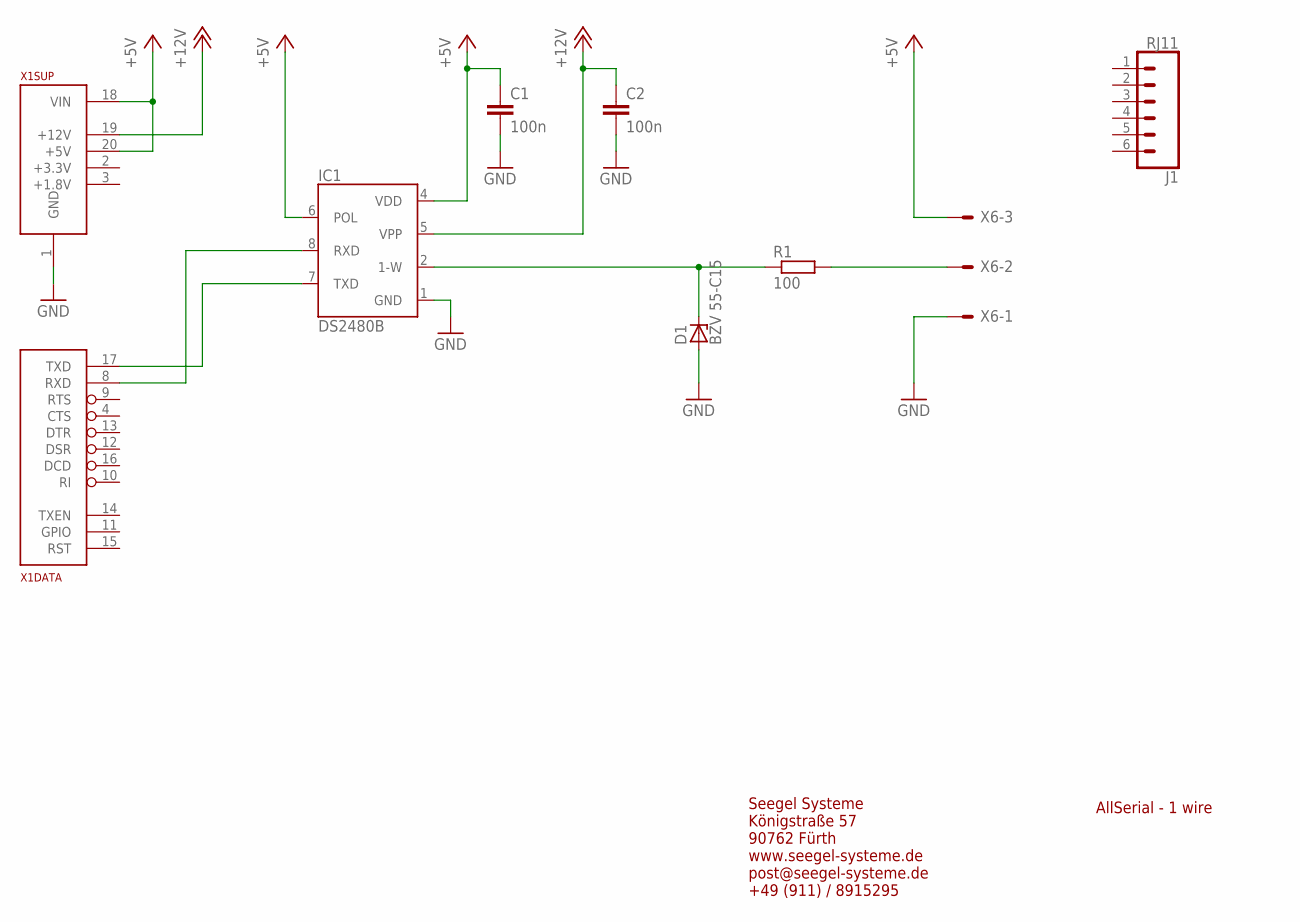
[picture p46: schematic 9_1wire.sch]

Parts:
C1, C2: 100n; C0805
D1: BZV 55-C15; SOD80C
IC1: DS2480B; SO08
J1: RJ11; RJ11-6
R1: 100; R0805
X1: ALLSERIALSLAVE; DAUGHTER-THT
X6: AKL18X-03W; AKL182-03

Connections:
+5V: C1.1, IC1.4 (VDD), IC1.6 (POL), X1.18 (VIN), X1.20 (+5V), X6.P$3
+12V: C2.1, IC1.5 (VPP), X1.19 (+12V)
GND: C1.2, C2.2, D1.A, IC1.1 (GND), X1.1 (GND), X6.P$1
unnamed: IC1.7 (TXD), X1.17 (TXD)
unnamed: IC1.8 (RXD), X1.8 (RXD)
unnamed: D1.C, IC1.2 (1-W), R1.1
unnamed: R1.2, X6.P$2

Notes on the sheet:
AllSerial - 1 wire
Seegel Systeme Königstraße 57 90762 Fürth www.seegel-systeme.de post@seegel-systeme.de +49 (911) / 8915295

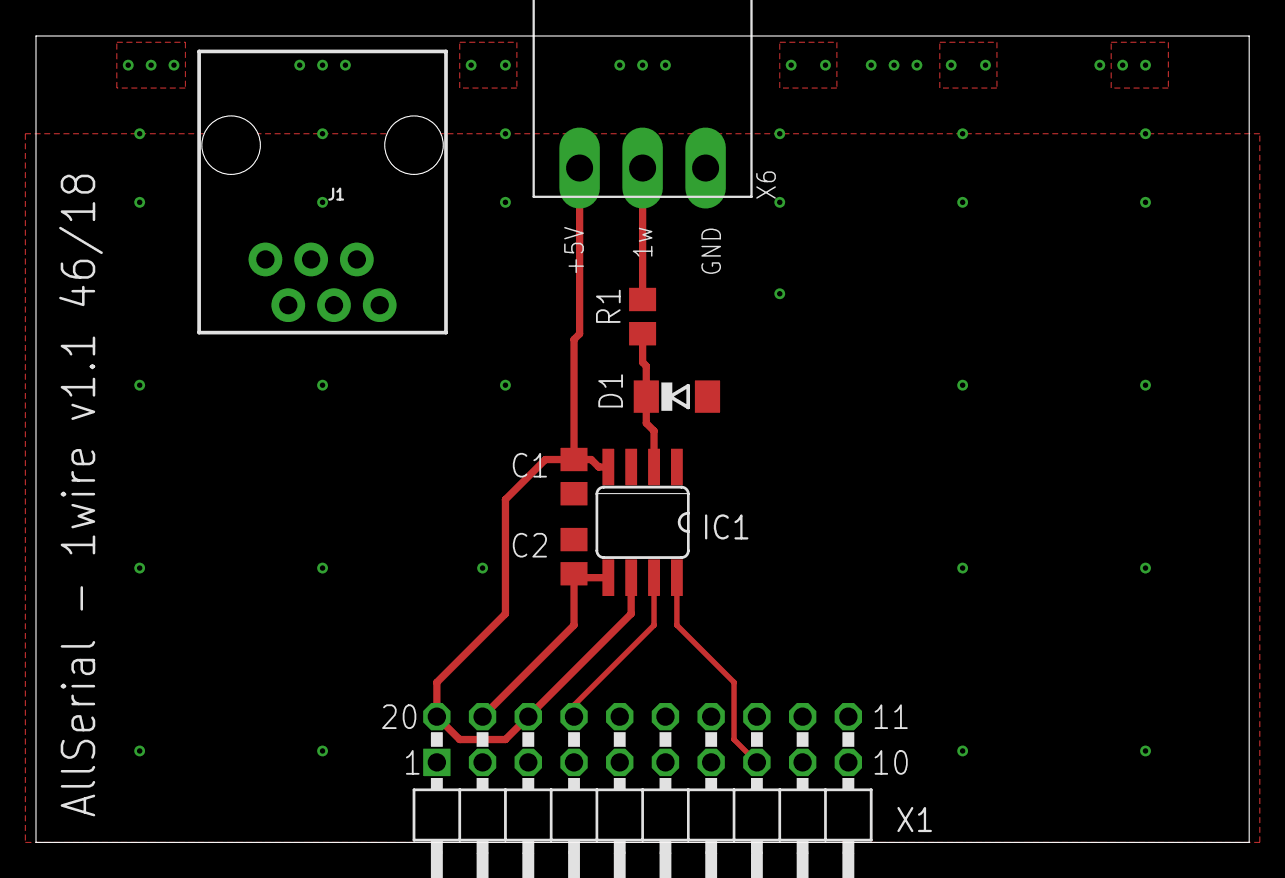
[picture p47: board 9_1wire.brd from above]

Board: 2 copper layers, 67.4 x 44.8 mm, 8 parts (0 on the bottom side), 7 nets.

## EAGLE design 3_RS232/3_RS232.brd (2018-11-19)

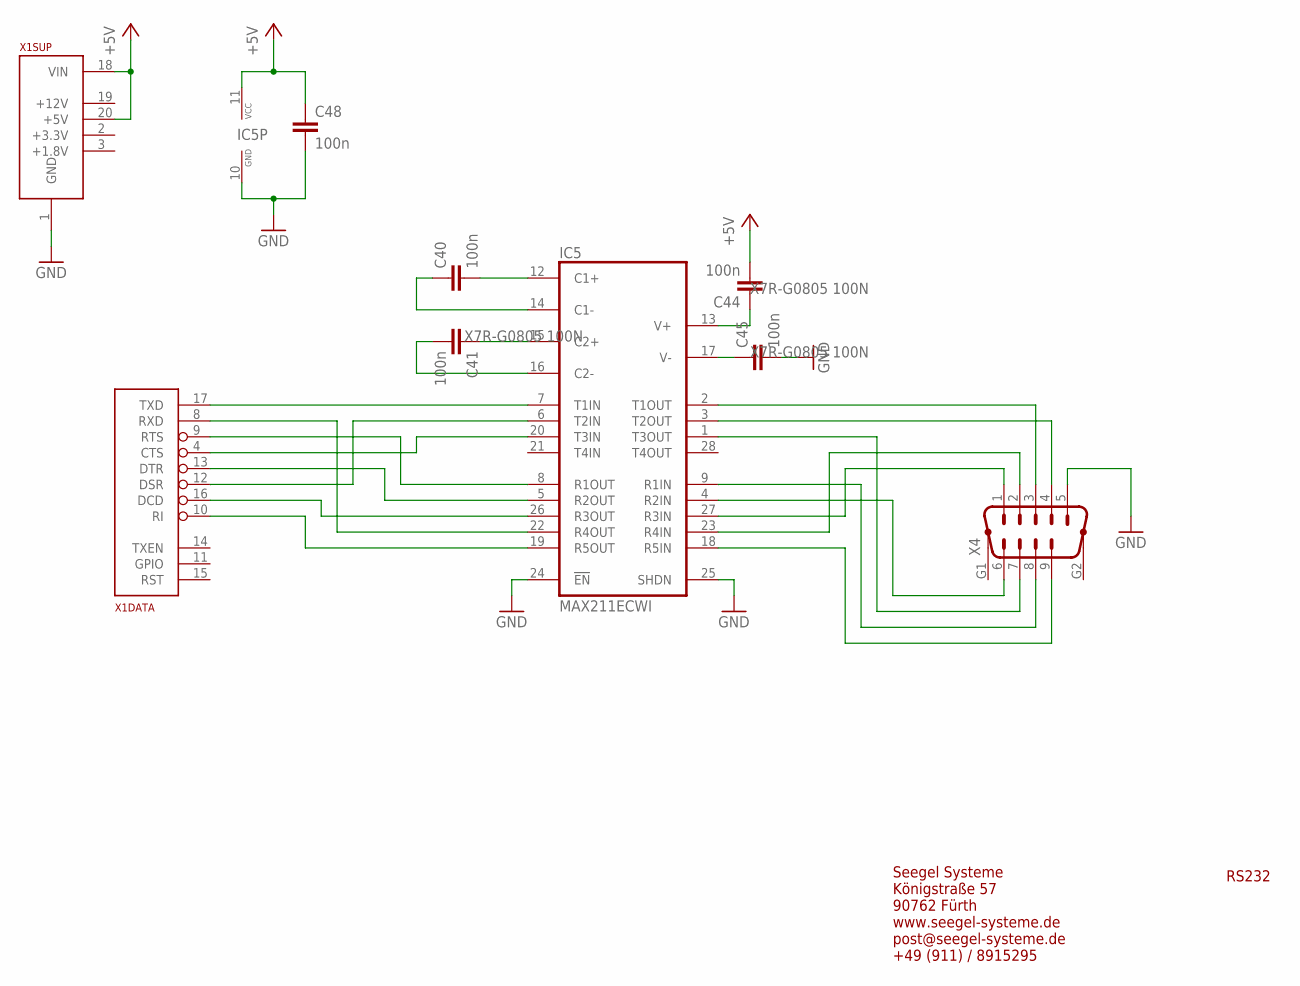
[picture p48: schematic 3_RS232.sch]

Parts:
C40, C41, C44, C45, C48: 100n; C0805
IC5: MAX211ECWI; SO28L
X1: ALLSERIALSLAVE; DAUGHTER-THT
X4: M09HP

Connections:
+5V: C44.2, C48.1, IC5.11 (VCC), X1.18 (VIN), X1.20 (+5V)
GND: C45.2, C48.2, IC5.10 (GND), IC5.24 (EN), IC5.25 (SHDN), X1.1 (GND), X4.5
unnamed: IC5.18 (R5IN), X4.9
unnamed: IC5.9 (R1IN), X4.8
unnamed: IC5.1 (T3OUT), X4.7
unnamed: IC5.4 (R2IN), X4.6
unnamed: IC5.27 (R3IN), X4.1
unnamed: IC5.23 (R4IN), X4.2
unnamed: IC5.2 (T1OUT), X4.3
unnamed: IC5.3 (T2OUT), X4.4
unnamed: C40.2, IC5.12 (C1+)
unnamed: C40.1, IC5.14 (C1-)
unnamed: C41.1, IC5.15 (C2+)
unnamed: C45.1, IC5.17 (V-)
unnamed: C44.1, IC5.13 (V+)
unnamed: C41.2, IC5.16 (C2-)
unnamed: IC5.7 (T1IN), X1.17 (TXD)
unnamed: IC5.22 (R4OUT), X1.8 (RXD)
unnamed: IC5.20 (T3IN), X1.4 (CTS)
unnamed: IC5.8 (R1OUT), X1.9 (RTS)
unnamed: IC5.26 (R3OUT), X1.16 (DCD)
unnamed: IC5.19 (R5OUT), X1.10 (RI)
unnamed: IC5.5 (R2OUT), X1.13 (DTR)
unnamed: IC5.6 (T2IN), X1.12 (DSR)

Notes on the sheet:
RS232
Seegel Systeme Königstraße 57 90762 Fürth www.seegel-systeme.de post@seegel-systeme.de +49 (911) / 8915295

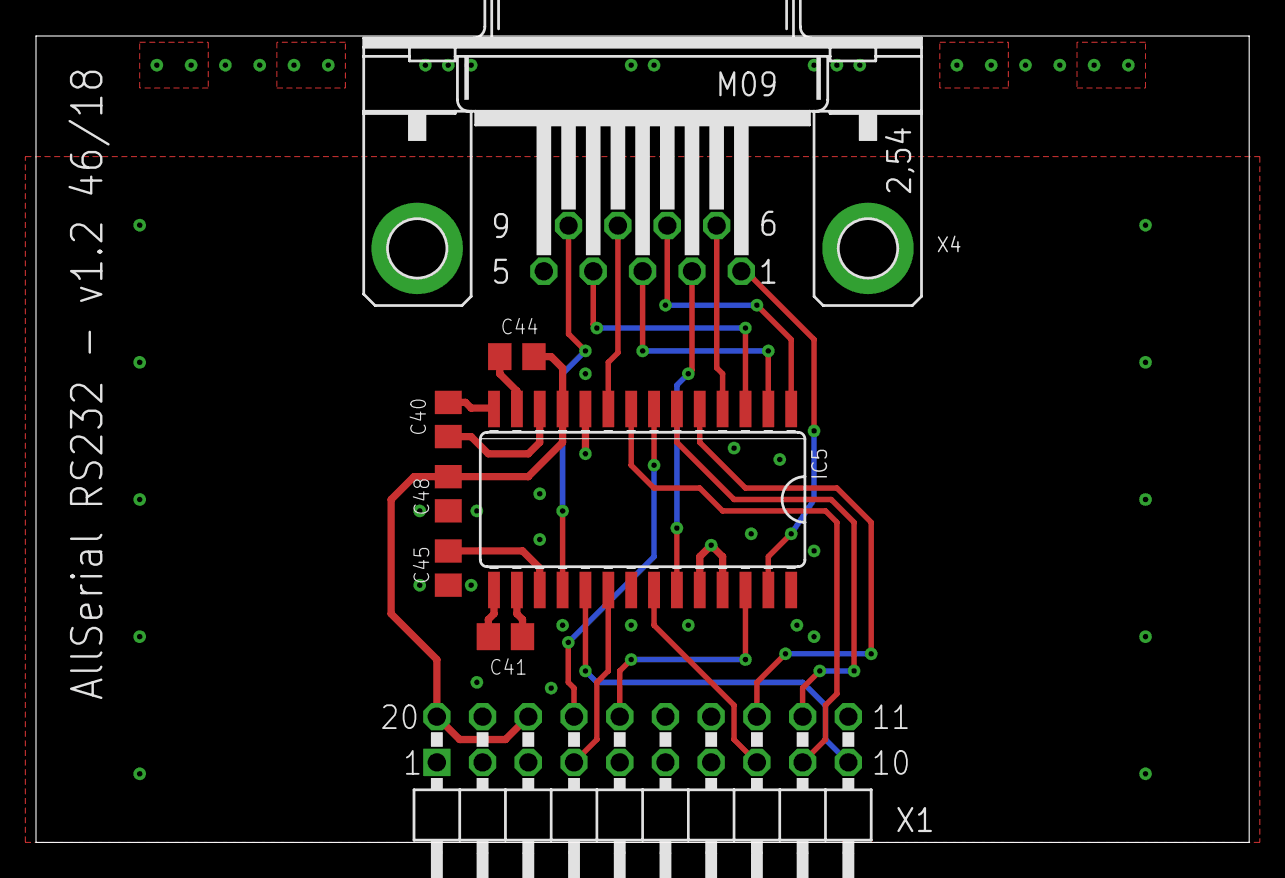
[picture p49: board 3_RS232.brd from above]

Board: 2 copper layers, 67.4 x 44.8 mm, 8 parts (0 on the bottom side), 24 nets.

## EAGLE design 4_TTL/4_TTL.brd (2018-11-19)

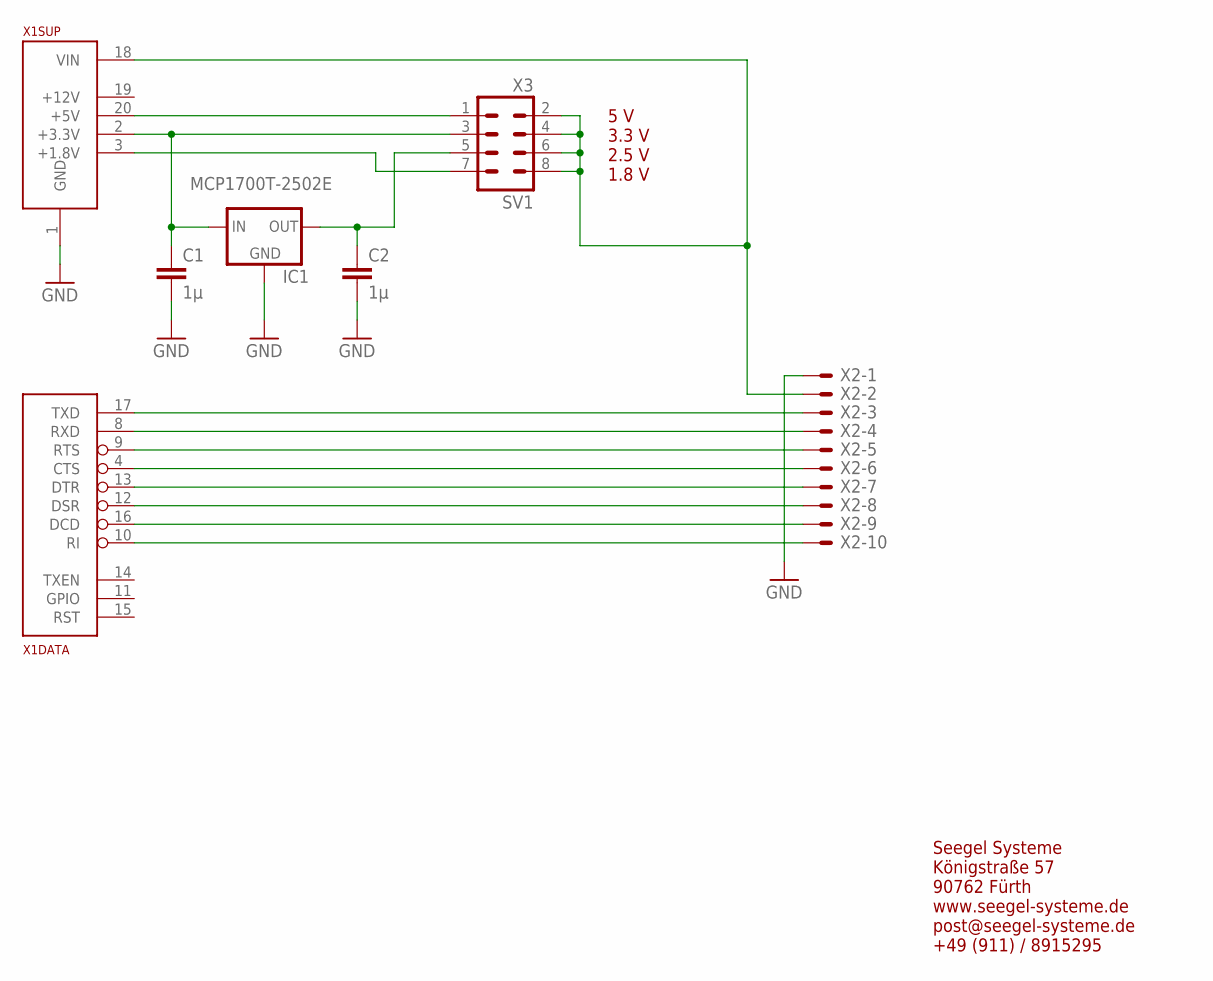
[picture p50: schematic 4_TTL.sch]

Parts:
C1, C2: 1µ; C0805K
IC1: MCP1700T-2502E; SOT23
SV1: X3; MA04-2W
X1: ALLSERIALSLAVE; DAUGHTER-THT
X2: AKL18X-10W; AKL182-10

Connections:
CTS4: X1.4 (CTS), X2.P$6
DCD4: X1.16 (DCD), X2.P$9
DSR4: X1.12 (DSR), X2.P$8
DTR4: X1.13 (DTR), X2.P$7
GND: C1.2, C2.2, IC1.1 (GND), X1.1 (GND), X2.P$1
unnamed: SV1.2, SV1.4, SV1.6, SV1.8, X1.18 (VIN), X2.P$2
unnamed: SV1.7, X1.3 (+1.8V)
unnamed: SV1.1, X1.20 (+5V)
unnamed: C1.1, IC1.3 (IN), SV1.3, X1.2 (+3.3V)
unnamed: C2.1, IC1.2 (OUT), SV1.5
RI4: X1.10 (RI), X2.P$10
RTS4: X1.9 (RTS), X2.P$5
RXD4: X1.8 (RXD), X2.P$4
TXD4: X1.17 (TXD), X2.P$3

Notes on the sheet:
5 V 3.3 V 2.5 V 1.8 V
Seegel Systeme Königstraße 57 90762 Fürth www.seegel-systeme.de post@seegel-systeme.de +49 (911) / 8915295

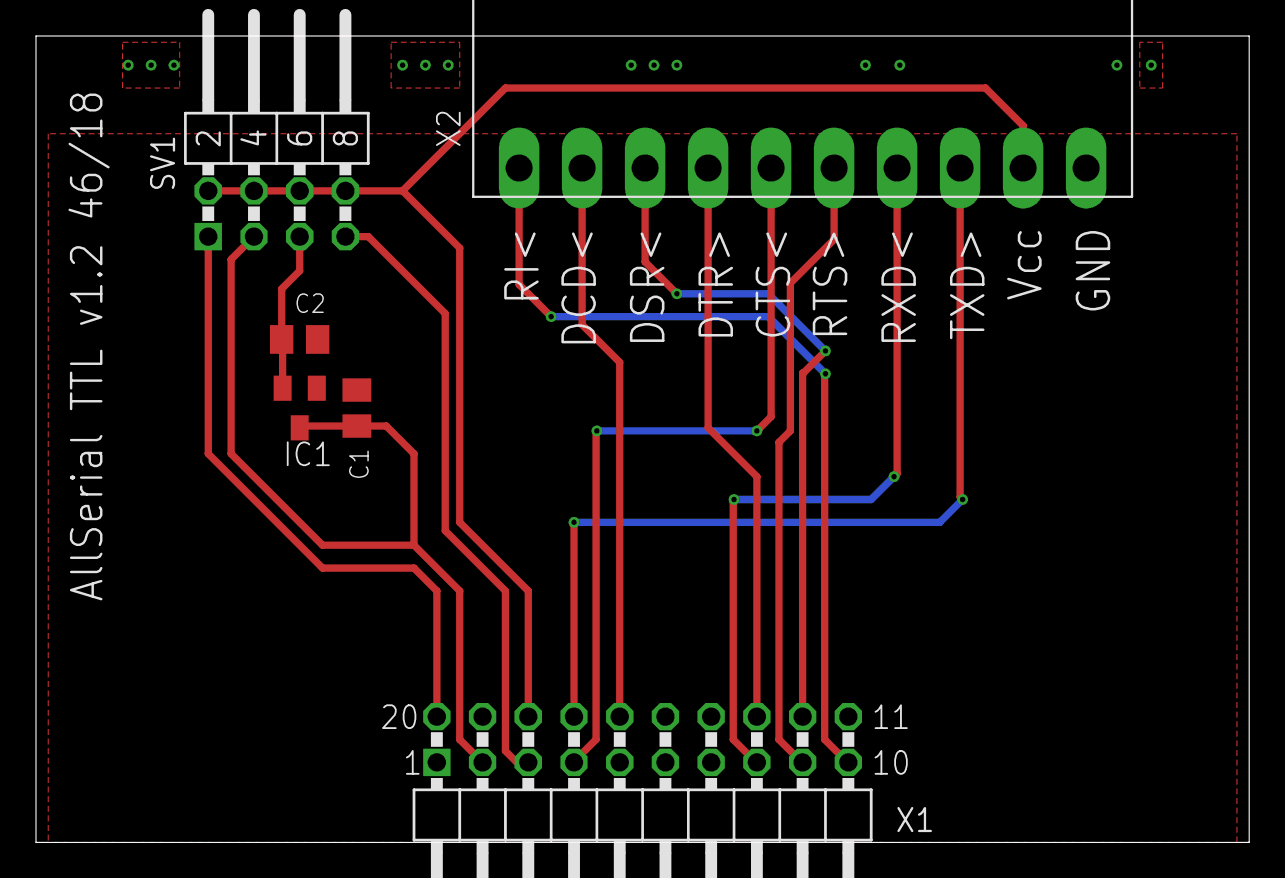
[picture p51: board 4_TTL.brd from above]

Board: 2 copper layers, 67.4 x 44.8 mm, 6 parts (0 on the bottom side), 14 nets.

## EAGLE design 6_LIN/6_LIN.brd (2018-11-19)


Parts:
C1: 220p; C0805
C14: 1µ; C0805
D1, D4: 1N4148; MINIMELF
D2: MMBZ27VAL; SOT23
D5: 43V; SOD80C
IC6: MCP2003; SOIC8T
J1: MA02-1W; MA02-W
R1: 4k7; R0805
R2: 47; R0805
R6: 1k; R0805
X1: ALLSERIALSLAVE; DAUGHTER-THT
X6: AKL18X-03W; AKL182-03

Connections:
+5V: IC6.2 (CS), R1.2, X1.18 (VIN), X1.20 (+5V)
+UB: D1.A, D4.A, X6.P$1
GND: C1.2, C14.2, D2.1 (K1), D5.A, IC6.3 (!WAKE), IC6.5 (VSS), IC6.TGND, X1.1 (GND), X6.P$3
unnamed: D1.C, R2.2
unnamed: D4.C, R6.2
unnamed: C14.1, D5.C, IC6.7 (VBB), R2.1
unnamed: C1.1, D2.2 (K2), IC6.6 (LBUS), J1.2, X6.P$2
unnamed: J1.1, R6.1
unnamed: IC6.4 (TXD), X1.17 (TXD)
unnamed: IC6.1 (RXD), R1.1, X1.8 (RXD)

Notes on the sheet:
AllSerial - LIN
Master
Seegel Systeme Königstraße 57 90762 Fürth www.seegel-systeme.de post@seegel-systeme.de +49 (911) / 8915295


Board: 2 copper layers, 67.4 x 44.8 mm, 13 parts (0 on the bottom side), 10 nets.

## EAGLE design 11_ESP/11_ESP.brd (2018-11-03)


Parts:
D1: STPS 2L40U STM; DO214AA
R2, R3: 10k; R0805
S1: 31-XX; B3F-31XX
SV1: ML6L
T1, T2: BC847; SOT23
X1: ALLSERIALSLAVE; DAUGHTER-THT

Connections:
+3V3: D1.A, X1.2 (+3.3V), X1.18 (VIN)
GND: S1.2 (S), SV1.6, X1.1 (GND)
unnamed: D1.C, SV1.2
unnamed: R3.1, T1.2 (E), X1.13 (DTR)
unnamed: SV1.3, T1.3 (C)
unnamed: S1.1, SV1.5, T2.3 (C)
unnamed: R2.1, T2.2 (E), X1.9 (RTS)
unnamed: SV1.1, X1.17 (TXD)
unnamed: R2.2, T1.1 (B)
unnamed: R3.2, T2.1 (B)
unnamed: SV1.4, X1.8 (RXD)

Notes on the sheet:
AllSerial - ESP Prog
Seegel Systeme Königstraße 57 90762 Fürth www.seegel-systeme.de post@seegel-systeme.de +49 (911) / 8915295

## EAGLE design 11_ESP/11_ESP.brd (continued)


Board: 2 copper layers, 67.4 x 44.8 mm, 8 parts (0 on the bottom side), 11 nets.

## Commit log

2018-07-07 adding schematic & images
2018-07-07 Corrected RST pin
2018-07-07 RS232 routing
    [AllSerial.brd, AllSerial.sch]
2018-07-07 board seperation
    [1_Main.brd, 1_Main.sch, 2_RS485_RS422.brd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]
2018-07-07 update lib
    [1_Main.brd, 1_Main.sch, 2_RS485_RS422.brd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]
2018-07-08 Improve lib
    Route RS232 board
    Route TTL board
    [1_Main.brd, 1_Main.sch, 3_RS232.brd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]
2018-07-10 finish LIN schematic
    [6_LIN.brd, 6_LIN.sch]
2018-07-12 update lib
    restructured
    [1_Main.brd, 1_Main.dxf, 1_Main.sch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]
2018-07-12 added mBus master
    [7_MBUS.brd, 7_MBUS.sch]
2018-07-12 updated readme & mainboard
    [1_Main.brd, 1_Main.sch]
2018-07-12 insert diode for supply
    [4_TTL.brd, 4_TTL.sch]
2018-07-17 Add 2mm front line
2018-07-17 finish FTDI PCB
    [1_Main.brd, 1_Main.sch]
2018-07-17 finish RS485 PCB
    [2_RS485_RS422.brd, 2_RS485_RS422.sch]
2018-07-17 fix connector for LA
    [1_Main.brd, 1_Main.sch]
2018-07-18 Add ESD protection
    [1_Main.brd, 1_Main.sch]
2018-07-18 Add BOM
    [1_MAIN_BOM.csv, 1_Main.brd]
2018-07-18 add and correct BOMs
    [1_MAIN_BOM.csv, 1_MAIN_BOM.ods, 1_Main.sch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]
2018-07-20 new BOMs,
    finish TTY board
    [4_TTL.brd, 4_TTL.sch, 5_TTY.brd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]
2018-07-20 add schematics
2018-07-25 Clean up
    [1_MAIN_BOM.ods, 1_Main.brd, 1_Main.dxf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]
2018-07-25 renaming, add front
    [1A_Main_FTDI.dxf, 1_MAIN_BOM.ods, 1_Main.brd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]
2018-07-25 add front
    [2_RS422_485.dxf]
2018-07-25 change diodes
    [3_RS232 FRONT.dxf, 3_RS232.dxf, 6_LIN.brd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]
2018-07-31 add author
    [3_RS232.brd, 3_RS232.sch, 4_TTL.brd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]
2018-09-01 change to libv2
    [2_RS485_RS422.brd, 2_RS485_RS422.sch, 4_TTL.brd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]
2018-09-21 new lib, change pinout!
    [1_MAIN_BOM.ods, 1_Main.brd, 1_Main.sch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]
2018-09-26 final design & order
    [1_MAIN_BOM.ods, 1_Main.brd, 1_Main.sch]
2018-09-26 use new lib
    [7_MBUS.brd, 7_MBUS.sch]
2018-10-01 Update BOM & pics
    [5_TTY.brd, 5_TTY_BOM.ods]
2018-10-01 Add order codes
    [1_Main.brd]
2018-10-01 update BOM
    [1_MAIN_BOM.ods]
2018-10-03 fix BOM for MAX211
    [3_RS232_BOM.ods]
2018-10-07 add eagle front boards
    [1_Main_Front.brd, 2_RS485_Front.brd, 3_RS232_Front.brd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]
2018-10-07 fix GND connection
    [3_RS232.brd, 3_RS232.sch]
2018-10-07 update boms
    [2_RS485_RS422_BOM.ods, 4_TTL_BOM.ods, 5_TTY_BOM.ods]
2018-10-09 update bills of material
    [2_RS485_RS422_BOM.ods, 3_RS232_BOM.ods, 4_TTL_BOM.ods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]
2018-10-09 Add front, update png, clean up
    [6_LIN_Front.brd]
2018-10-12 BOM updates
    [1A_MAIN_BOM.ods, 1A_Main.brd, 1A_Main.sch]
2018-10-15 correct connector labels
    [6_LIN_Front.brd]
2018-10-23 add pdf docs
    add gerber data
    cleanup
    renaming
    [1A_MAIN.brd, 1A_MAIN.sch, 1A_MAIN_FRONT.brd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]
2018-10-30 added 10 arduino module
    [10_ARDUINO.brd, 10_ARDUINO.sch]
2018-10-30 add 1wire files
    [9_1wire.brd, 9_1wire.sch, 9_1wire_Front.brd]
2018-10-30 add front boards
    [1A_Main_Front.brd, 2_RS485_Front.brd, 3_RS232_Front.brd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]
2018-11-03 adding 1wire and eBus boards
    [8_EBUS.brd, 8_EBUS.csv, 8_EBUS.sch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]
2018-11-03 add ESP & arduino board
    [10_ARDUINO_Front.brd, 11_ESP.brd, 11_ESP.sch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]
2018-11-19 pro mini layout corrected
    [10_ARDUINO.brd, 10_ARDUINO.sch, 10_ARDUINO_Front.brd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]
2018-11-19 Revert "pro mini layout corrected"
    This reverts commit e6acf7b114fc184efa746b3a51c54623d1353390.
    [10_ARDUINO.brd, 10_ARDUINO.sch, 10_ARDUINO_Front.brd]
2018-11-19 Use lib elements
    [11_ESP.brd, 11_ESP_FRONT.brd]
2018-11-19 Cleanup, front with lib elements
    [1A_MAIN.sch, 1A_MAIN_BOM.ods, 1A_MAIN_FRONT.brd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]
2018-11-19 Revert "Cleanup, front with lib elements"
    This reverts commit d2aae2c670d4479654c143ea750e88e2046a00ae.
    [1A_MAIN_BOM.ods, 1A_MAIN_FRONT.brd, 1A_MAIN_FTDI_ASSEM_BOM.xlsx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]
2018-11-19 Cleanup, front lib elements
    [2_RS485_FRONT.brd, 2_RS485_Front.brd, 2_RS485_RS422.brd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]
2018-11-19 cleanup & update docu
    [7_MBUS.brd, 7_MBUS.sch, USB_Serial_Bridge.brd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]

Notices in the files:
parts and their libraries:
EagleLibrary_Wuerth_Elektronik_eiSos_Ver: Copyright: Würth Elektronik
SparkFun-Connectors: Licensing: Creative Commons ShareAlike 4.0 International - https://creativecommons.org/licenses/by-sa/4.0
